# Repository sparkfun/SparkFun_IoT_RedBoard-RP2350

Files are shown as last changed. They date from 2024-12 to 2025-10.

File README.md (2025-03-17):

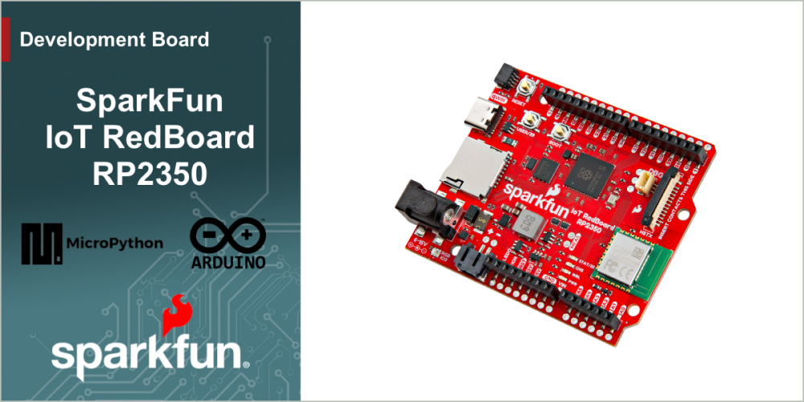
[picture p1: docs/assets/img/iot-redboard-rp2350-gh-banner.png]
SparkFun IoT RedBoard - RP2350) SparkFun IoT RedBoard - RP2350 (https://www.sparkfun.com/sparkfun-iot-redboard-rp2350.html)


[*SparkFun IoT RedBoard - RP2350 (WRL-27708)*](https://www.sparkfun.com/sparkfun-iot-redboard-rp2350.html)

The SparkFun IoT Redboard - RP2350 combines the RP2350 microcontroller with the Raspberry Pi Radio Module 2 to provide a powerful and versatile wireless development platform in the Arduino R4 form factor. This IoT Redboard also includes integrated battery power and charging circuits, &micro;SD card slot, Qwiic connector, 3-pin debug header as well as a 22-pin ribbon cable connector tied to the RP2350's HSTX (high-speed transmit) pins. The board shares a pinout between female headers and matching 0.1"-spaced plated through-hole (PTH) headers to allow you to choose between temporary or soldered connections. 

Repository Contents
-------------------

* **/Documentation** - Data sheets, additional product information
* **/Examples** - Example code
* **/Hardware** - Eagle design files (.brd, .sch)
* **/docs** - GitHub Pages documentation files

Documentation
--------------

* **[Hookup Guide](https://docs.sparkfun.com/SparkFun_IoT_RedBoard-RP2350/)** - Basic hookup guide for the SparkFun IoT RedBoard - RP2350.

Product Versions
----------------

* [WRL-27708](https://www.sparkfun.com/sparkfun-iot-redboard-rp2350.html) - Initial release of the IoT RedBoard - RP2350

License Information
-------------------

This product is ***open source***!

Please review the LICENSE.md file for license information.

If you have any questions or concerns on licensing, please contact technical support on our [SparkFun forums](https://forum.sparkfun.com/viewforum.php?f=152).

Distributed as-is; no warranty is given.

* Your friends at SparkFun.

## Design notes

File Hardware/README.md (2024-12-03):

SparkFun <PRODUCT NAME> Design Files
=====================================

The .sch and .brd files hare are Eagle CAD schematic and PCB design files from SparkFun Electronics.
A freeware version of Autodesk Eagle can be found [here](https://www.autodesk.com/products/eagle/free-download).

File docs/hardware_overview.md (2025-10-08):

This document gives a detailed overview of the RedBoard IoT - RP2350 and all components present on the board.

## IoT RedBoard - RP2350 Overview

The IoT RedBoard - RP2350 is packed with hardware aimed at helping users get the most out of the RP2350. This includes multiple power inputs like USB-C and a 2-pin JST connector, Qwiic connector, standard R3 female headers, several status LEDs and also a couple specialized headers for the RP2350's high-speed transmit (HSTX) pins and its debug pins. The photo below highlights most of the major components on this board that we'll cover in this Hardware Overview.

<figure markdown>
Photo highlighting major components on the IoT RedBoard - RP2350
</figure>

## RP2350 Microcontroller

The RP2350 from Raspberry Pi packs a whole lot of computing punch in a tiny package. The RP2350 is a unique dual-core microcontroller that has <i>four</i> internal processors (two Arm Cortex-M33 and two Hazard3 RISC-V processors @150 MHz), though you can only select any two of these four to run at the same time. 

This internal configuration allows users to customize the chip to use a pair their preferred architecture (ARM or Hazard3) or to use one of each! The RP2350 includes 520kB of on-chip SRAM in ten independent banks, 8kB of one-time-programmable (OTP) storage and this board also includes PSRAM connected to the chip's QSPI bus. The RP2350 also has a bevy of security features including optional boot signing with protected OTP storage for the boot decryption key, global bus filtering (based on either Arm or RISC-V security and privilege levels) and more.

The RedBoard IoT - RP2350 uses the "B" version of the microcontroller which has 48 5V-tolerant GPIO with 8 analog inputs and also includes the following peripheral options:

* 2x UART
* 2x SPI
* 2x I<sup>2</sup>C
* 24 PWM
* USB 1.1 Controller
* 12 PIO State Machines
* 1x High-Speed Transmit (HSTX) Peripheral for DVI/DSI support

For complete information on the RP2350, refer to the [datasheet](./assets/component_documentation/rp2350-datasheet.pdf).

## Memory

### W25Q128 Flash

The W25Q128 Flash IC adds 16MB of storage space on the RedBoard IoT. This connects to the RP2350 over QSPI.

### PSRAM

The board also includes an 8MB PSRAM IC for dynamic storage. This also connects to the RP2350 over QSPI. PSRAM support is included in the SparkFun MicroPython "early release" firmware found later in this guide and on the product page, but is not natively supported in the Pico SDK as of release. Refer to the Arducam Demo section of this guide for information on how to enable and set up PSRAM using the Pico SDK.

For a complete overview of the PSRAM IC, refer to the [datasheet](./assets/component_documentation/APS6404L_3SQR_Datasheet.pdf).

### &micro;SD Card Slot

The board has a &micro;SD card slot that connects to the RP2350's SPI bus for even more storage. Make sure the SPI are **LOW** when the &micro;SD card is **unpowered**. Setting these pins **HIGH** can damage the GPIO pins. The connector is a fricton-fit connector so no "clicking" and "unclicking" is necessary. Just plug it in nice and snug. 

## Raspberry Pi RM2 Radio Module

The Raspberry Pi RM2 (radio module 2) is built around the same chipset as the previous Raspberry Pi radio module found on boards like the Pico W. The module features both WiFi 4 (802.11n) 2.4GHz and  Bluetooth<sup>&trade;</sup> 5.2 with support for Low Energy (Central and Peripheral) and Classic. 

The RM2 communicates with the RP2350 over SPI and we've designed this board to use the same pins for the radio module as official Raspberry Pi boards (Pico W and Pico 2 W), making it easy to use the radio module without having to adjust anything from those development boards. The RedBoard IoT routes the module's GPIO0 pin to a blue STAT LED to allow users to create a visual indicator of the status of the module. We added this STAT LED connected to the same pin used on the Pico W to make code for that compatible with the RedBoard IoT - RP2350.

## Power

The RedBoard IoT - RP2350 includes several options for powering including USB-C, LiPo battery with on-board battery charging and monitoring circuits as well as direct power inputs.

### USB-C

The USB-C connector on the board acts as the primary serial interface for the RP2350 as well as a power input. The <b>5V</b> USB input voltage is regulated down to <b>3.3V</b> through a voltage regulator with a max current of <b>500mA@3.3V</b>.

### Barrel Jack

The barrel jack connector on this board accepts a supply voltage between <b>7V</b> and <b>15V</b>. This supply voltage includes a <b>16V/2.5A/5A</b> fuse.

### LiPo Power & Charging

The IoT RedBoard - RP2350 can also be powered with a single cell lithium battery through a 2-pin JST connector. The board also includes a MCP73831 LiPo charge IC as part of a charging circuit for a connected battery. The charge rate is set to <b>455mA</b> and is powered either via USB, barrel jack or dedicated pin. 

It also has a MAX17048 battery fuel gauge to monitor a connected battery's voltage level. The fuel gauge communicates with the RP2350 over I<sup>2</sup>C.

## Pinout

### R3 Footprint Female Headers

### HSTX Connector

### RP2350 Debug Connector

We've also included a dedicated 1mm 3-pin connector tied to the RP2350's debug pins (SWDIO, SWCK & Ground). Users can plug a [debug cable (link needed - ML)]() to this connector. These pins are also connected to a 0.1"-spaced PTH header right next to it for those who prefer a different connection type. 

## LEDs

This board has four LEDs labeled <b>STAT/25</b>, <b>CHG</b>, <b>WRL</b>, <b>PWR</b> and <b>RGB/IO3</b>.

**Photo highlighting LEDs - ML**

The list below outlines the color and functionality of the LEDs on the IoT RedBoard - RP235.

* <b>STAT/25</b> - Blue LED tied to the RP2350's IO25. User-programmable status LED. 
* <b>CHG</b> - Yellow LED connects to the MCP73831 LiPo charge IC to indicate when an attached battery is being charged.
* <b>WRL</b> - Blue LED tied to IO0 on the RM2. User-programmable status LED.
* <b>PWR</b> - Red LED tied to <b>3.3V</b> power circuit.
* <b>RGB/IO3</b> - WS2812 RGB LED tied to the RP2350's IO3. User-progammable RGB LED.

## Buttons

There are three push buttons on the board labeled <b>RESET</b>, <b>USER/36</b> and <b>BOOT</b>.

**Photo highlighting buttons - ML**

The <b>RESET</b> button connects to the RP2350's RUN pin and resets the RP2350 when pressed. The <b>USER/36</b> button connects to IO36 on the RP2350 and can act as a physical input to trigger an event in code. The <b>BOOT</b> button 

## Solder Jumpers

The IoT RedBoard - RP2350 has five solder jumpers labeled <b>PWR</b>, <b>LP</b>, <b>SHLD</b>, <b>I2C</b> and <b>BYP</b>. 

**Photo highlighting solder jumpers - ML**

The list below outlines the solder jumpers functionality, default state and any notes about their behavior.

* <b>PWR</b> - Completes the Power LED circuit. CLOSED by default. Open to disable the power LED to help conserve power.
* <b>LP</b> - Pulls the RP9080 3.3V regulator's enable (EN) pin HIGH (3.3V) to power the peripheral (3.3V_P) power circuit. CLOSED by default. While enabled, this provides power to the &micro;SD card and RGB LED. Open to disable the peripheral power circuit.
* <b>SHLD</b> - Nets the USB-C Shield pin to the board's ground plane. CLOSED by default. Open to isolate the shield pin from the board's ground.
* <b>I2C</b> - Three-way jumper pulls the I<sup>2</sup>C pins (IO4/SDA and IO5/SCL) to <b>3.3V</b> through a pair of <b>2.2k&ohm;</b> resistors. CLOSED by default. Open the jumper to disable the pullups on these pins.
* <b>BYP</b> - Fuse bypass jumper. OPEN by default. Close to bypass the fuse on the VIN input.

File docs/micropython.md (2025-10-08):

## Setup

MicroPython is an application of the Python 3 language that runs on microcontrollers like the IoT RedBoard - RP2350 that allows you to easily interact with the board directly over a USB serial interface through either a command line interface or your preferred Python IDE such as [Thonny](https://thonny.org/). We'll do a quick overview of how to download MicroPython firmware on to the RedBoard IoT - RP2350 but for a complete overview of using MicroPython with this and other RP2350 boards, head over to Raspberry Pi's documentation by clicking the button below:

<article style="text-align: center;" markdown>
[Raspberry Pi MicroPython Docs](https://www.raspberrypi.com/documentation/microcontrollers/micropython.html){ .md-button .md-button--primary}
</article>

## UF2 Firmware

The SparkFun IoT RedBoard - RP2350 ships with MicroPython firmware pre-loaded so you do not need to download and install it in your board. If you need to update the firmware at any point, it is available in the main release of MicroPython [here](https://micropython.org/download/). Search for "SparkFun IoT RedBoard - RP2350" on the MicroPython downloads page for the correct firmware. This release does **not** include PSRAM support; if your project requires using PSRAM, you can find a Beta release MicroPython firmware available [here](https://github.com/sparkfun/micropython/releases).

Download the latest release and then put the IoT RedBoard - RP2350 into UF2 bootloader mode and open the location the board appeared as a USB storage device (it should appear as "RP2350"). Next, drag and drop the UF2 file into the RP2350 folder and the board should reboot. After the board reboots, open up your preferred MicroPython IDE (or command line interface) and you can start interacting with your RedBoard IoT. Head over to the Quick Start guide for an example project that shows how to connect the board to a WiFi network, download data from a website and control the RGB LED.

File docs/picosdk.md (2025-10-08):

## Pico SDK Setup & Documentation

The Pico C SDK is a C/C++ development kit for Raspberry Pi microcontrollers including the RP2350. Click on the links below for complete documentation on installing and using the SDK.

<article style="text-align: center;" markdown>
[Pico C SDK Documentation](https://www.raspberrypi.com/documentation/pico-sdk/){ .md-button .md-button--primary }
</article>

<article style="text-align: center;" markdown>
[Pico C SDK GitHub Repository](https://github.com/raspberrypi/pico-sdk){ .md-button .md-button--primary }
</article>

### RedBoard IoT - RP2350 Board Definition

When using the Pico SDK, make sure to use v2.1 or later and select `sparkfun_iotredboard_rp2350` for the board. We recommend using [Microsoft VS Code](https://code.visualstudio.com/) with the [Pico SDK Extension](https://marketplace.visualstudio.com/items?itemName=raspberry-pi.raspberry-pi-pico).

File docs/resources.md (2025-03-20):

For more information on the SparkFun IoT RedBoard - RP2350, check out the following resources:

* [Schematic (PDF)](./assets/board_files/SparkFun_IoT_RedBoard-RP2350.pdf)
* [KiCad Files (ZIP)](./assets/board_files/SparkFun_IoT_RedBoard-RP2350.zip)
* [Board Dimensions](./assets/board_files/SparkFun_IoT_RedBoard-RP2350-Dimensions.jpg)
* [RP2350 Datasheet](./assets/component_documentation/rp2350-datasheet.pdf)
* [GitHub Repository](https://github.com/sparkfun/SparkFun_IoT_RedBoard-RP2350)

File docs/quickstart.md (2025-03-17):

Welcome to the SparkFun IoT RedBoard - RP2350 Quick Start Guide showing how to set up and use the RM2 wireless chip to connect to a WiFi network, request and download data on the number and names of astronauts currently on the International Space Station. 

If you're not familiar with using development boards or the development environments covered in this guide, refer to the [Hardware](./hardware_overview.md) & [Software](./uf2.md) sections for a detailed overview of the board along with instructions on setting up and programming the IoT RedBoard - RP2350.

## Basic Assembly

Start by plugging the IoT RedBoard - RP2350 into your computer using a USB-C connector. 

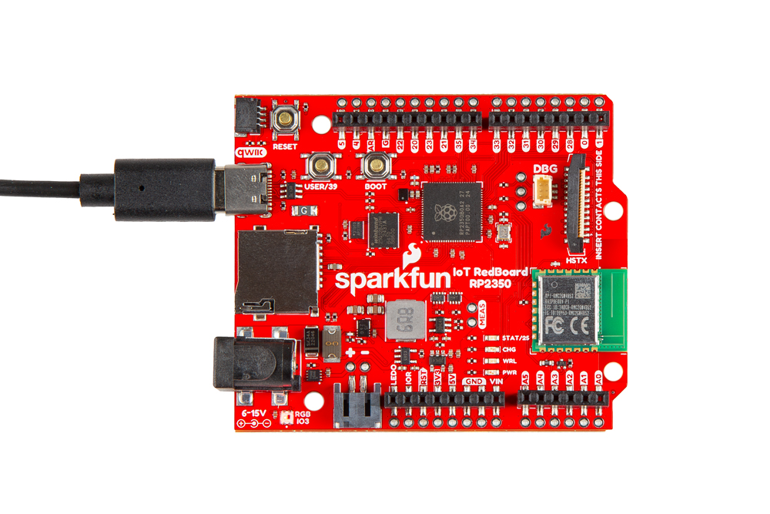
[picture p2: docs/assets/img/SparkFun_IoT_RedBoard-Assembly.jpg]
Photo showing RedBoard IoT - RP2350 connected over USB-C


## Code Examples

The following examples for both MicroPython and Arduino can be found in the Examples folder [here](https://github.com/sparkfun/SparkFun_IoT_RedBoard-RP2350/tree/main/Examples) in the GitHub repository. They demonstrate how to connect the IoT RedBoard - RP2350 to a WiFi network and then request and download data on the number of astronauts currently in space. They also include a visual indicator of the connection status using the RGB LED on the board like the photos below show:

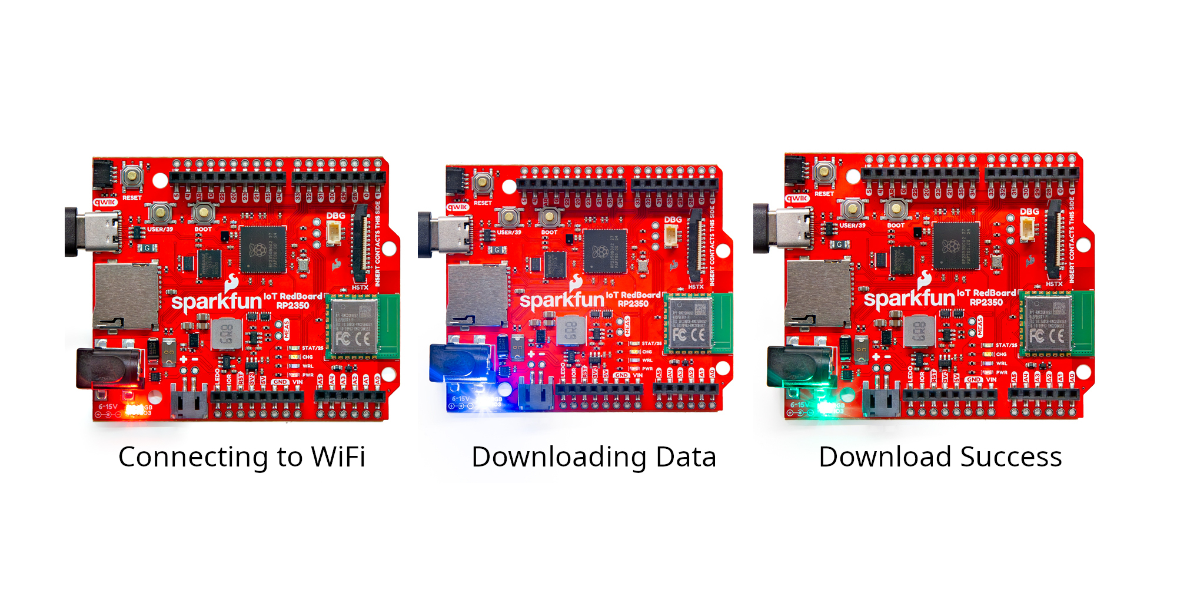
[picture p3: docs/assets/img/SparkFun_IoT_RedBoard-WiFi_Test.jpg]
Photo showing RGB LED indications during WiFi test.


### MicroPython

The IoT RedBoard - RP2350 ships with MicroPython firmware pre-loaded on the board. If needed, you can find the latest release of the firmware [here](https://github.com/sparkfun/micropython/releases). Open and run the Astronaut Network Demo in MicroPython by following these steps:

* Ensure you have a Python IDE like [Thonny](https://thonny.org/) installed or use a Command Line Interface (CLI) if you prefer.
* Download and open the [Astronaut Network Demo](https://github.com/sparkfun/SparkFun_IoT_RedBoard-RP2350/blob/main/Examples/Astronaut_Network_Demo_mpy/Astronaut_Network_Demo_mpy.py) in your preferred Python IDE (or CLI).
* Adjust values for `WIFI_NETWORK` and `WIFI_PASSWORD` to your network's credentials.
* Run the example.
* Watch the serial print out for status updates along with the RGB cycling from red to blue and then green.

**Code to Note**:

* Required modules for the example:
``` py
import network
import urequests
import time
import neopixel
import machine
```

* LED control. Values are (R,G,B) 0-255. This sets the LED to full Red:
``` py
led[0] = (255, 0, 0)
led.write()
```

* WiFi network connection. Enter values for network ID and password:
```py
wlan = network.WLAN(network.STA_IF)
wlan.active(True)
wlan.connect('WIFI_NETWORK', 'WIFI_PASSWORD')
```
Serial print and download request for the list of astronauts currently in space: 
```py
print('Downloading list of astronauts currently in space...')
astronauts = urequests.get("https://corquaid.github.io/international-space-station-APIs/JSON/people-in-space.json").json()
```

* Serial print of the number of and names of astronauts:
```py
# Print the number of astronauts and their names
number = astronauts['number']
print('There are', number, 'astronauts in space.')
for i in range(number):
    print(i+1, astronauts['people'][i]['name'])
```

### Arduino IDE

Run the Astronaut Network Demo using the [Arduino IDE](https://www.arduino.cc/en/software) by following these steps:

* Download and open the [Astronaut Network Demo](https://github.com/sparkfun/SparkFun_IoT_RedBoard-RP2350/blob/main/Examples/Astronaut_Network_Demo/Astronaut_Network_Demo.ino) sketch in Arduino.
* Open the [Board Manager](https://docs.arduino.cc/software/ide-v2/tutorials/ide-v2-board-manager/) and search for "Arduino Pico" to install the [Arduino-Pico](https://github.com/earlephilhower/arduino-pico) package.
* Open the [Library Manager](https://docs.arduino.cc/software/ide-v2/tutorials/ide-v2-installing-a-library/) and search for "FastLED" to install the [FastLED Arduino Library](https://github.com/FastLED/FastLED)
* Adjust the WiFi variables ("SSID" and "PASSWORD") to your network's credentials.
* Select the board (SparkFun IoT RedBoard - RP2350) and Port and click the "Upload" button.
* On upload completion, open the [Serial Monitor](https://docs.arduino.cc/software/ide-v2/tutorials/ide-v2-serial-monitor/) with the baud set to **115200** and watch the serial printout along with the RGB LED cycling from red to blue and then green.

The example includes several serial prints to indicate success or failure. If the code fails at any point, refer to the associated serial print to help identify where it failed and why.

**Code to Note**:

* WiFi network variables. Adjust "SSID" and "PASSWORD" to your WiFi network's ID and password:
```c++
#ifndef STASSID
#define STASSID "SSID"
#define STAPSK  "PASSWORD"
#endif // !STASSID
```

* WS2812 LED pin definition and settings:
```c++
#define NUM_LEDS 1
#define DATA_PIN PIN_NEOPIXEL
#define LED_TYPE WS2812
#define COLOR_ORDER GRB
#define LED_BRIGHTNESS 30
```

* Attempt to connect to WiFi network:
```c++
multi.addAP(ssid, password);

    if(multi.run() != WL_CONNECTED) {
        Serial.println(F("Unable to connect to network, rebooting in 10 seconds..."));
        delay(10000);
        rp2040.reboot();
    }

    Serial.println(F("Connected to network"));
    Serial.println(F("IP address: "));
    Serial.println(WiFi.localIP());
```

* Send HTTP get request:
```c++
 client.println(F("GET /international-space-station-APIs/JSON/people-in-space.json HTTP/1.0"));
    client.println(F("Host: corquaid.github.io"));
    client.println(F("Connection: close"));
```

* Parse JSON request:
```c++
JsonDocument doc;
    DeserializationError error = deserializeJson(doc, client);
    if(error) {
        Serial.print(F("deserializeJson() failed: "));
        Serial.println(error.f_str());
        client.stop();
        return;
    }
```

* Print number & names of astronauts in space:
```c++
int numberOfPeople = doc[F("number")];

    Serial.print(F("There are "));
    Serial.print(numberOfPeople);
    Serial.println(F(" astronauts in space."));

    for(JsonObject people_item : doc[F("people")].as<JsonArray>()) {
        int people_item_id = people_item[F("id")];
        const char* people_item_name = people_item[F("name")];
        Serial.print(people_item_id);
        Serial.print(F(": "));
        Serial.println(people_item_name);
    }
```

## Going Further

If you're looking for more detailed information on the design and components on this IoT Redboard, read on to the Hardware section below. Similarly, the Software tab includes detailed instructions on installing and using all supported development environments along with a few more examples for each IDE. Finally, the Resources section includes the board design files and datasheets for major components on the board.

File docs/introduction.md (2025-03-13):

SparkFun IoT RedBoard - RP2350) SparkFun IoT RedBoard - RP2350

The IoT RedBoard - RP2350 combines the RP2350 microcontroller with the Raspberry Pi Radio Module 2 to provide a powerful and versatile wireless development platform in the Arduino R4 form factor. In this guide we'll cover how to connect the IoT RedBoard - RP2350 to a computer and how to progam it three development environments: Raspberry Pi Pico SDK, MicroPython, or Arduino.

This guide uses just the hardware present on the IoT RedBoard - RP2350 so in order to follow along with this tutorial you'll only need the following items:

* [IoT RedBoard - RP2350](https://www.sparkfun.com/sparkfun-iot-redboard-rp2350.html)
* [USB-C Cable](https://www.sparkfun.com/usb-a-to-usb-c-cable-1m-usb-2-0-flexible-silicone.html)

## Topics Covered

This document contains three main sections: **Quickstart Guide**, **Hardware** and **Software**. 

The Quickstart Guide assumes a working knowledge of how to use a development board and the required software to program them for your project's needs. It covers a quick assembly and then jumps right into getting the necessary software packages installed to start uploading code in just a few short minutes.

The Hardware page provides a detailed overview of the IoT RedBoard - RP2350 along with all the major components included on the board. Refer to this page for information on things like the RP2350, LEDs, pinout and solder jumpers.

The Software pages are split into each supported development environment along with a page that goes into detail on what the UF2 bootloader is and how to use it on the IoT RedBoard - RP2350. Each software page gives instructions on how to download install its respective development environment, any necessary support packages including board definitions and, where necessary, library packages.

## Resources and Support Documentation 

You'll find the board design files (KiCad files & schematic), relevant documentation (datasheets, white papers, etc.) and other helpful links in the **Resources**. Lastly, the **Support** section includes a Troubleshooting page that includes any helpful tips specific to this board as well as information on how to receive technical support from SparkFun.

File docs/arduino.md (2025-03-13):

!!! attention
	If this is your first time using Arduino, please read through our tutorial on [installing the Arduino IDE](https://learn.sparkfun.com/tutorials/installing-arduino-ide). If you have not installed an Arduino library before, we recommend you check out our [installation guide](https://learn.sparkfun.com/tutorials/installing-an-arduino-library).

## Arduino-Pico Boards

The SparkFun IoT RedBoard - RP2350 is supported on the Arduino IDE in the [Arduino-Pico](https://github.com/earlephilhower/arduino-pico) boards package. To install the package, open the Preferences menu by navigating to <b>File</b> > <b>Preferences</b>. Look at the bottom of the Preferences menu for "Additional boards manager URLS" and then copy this JSON link into that field:

<code>
    https://github.com/earlephilhower/arduino-pico/releases/download/global/package_rp2040_index.json
</code>

Click "OK" to close this menu then navigate to the Boards Manager tool and search for "pico" and download the latest release of "Raspberry Pi Pico" (4.2.1 or later).

<figure markdown>
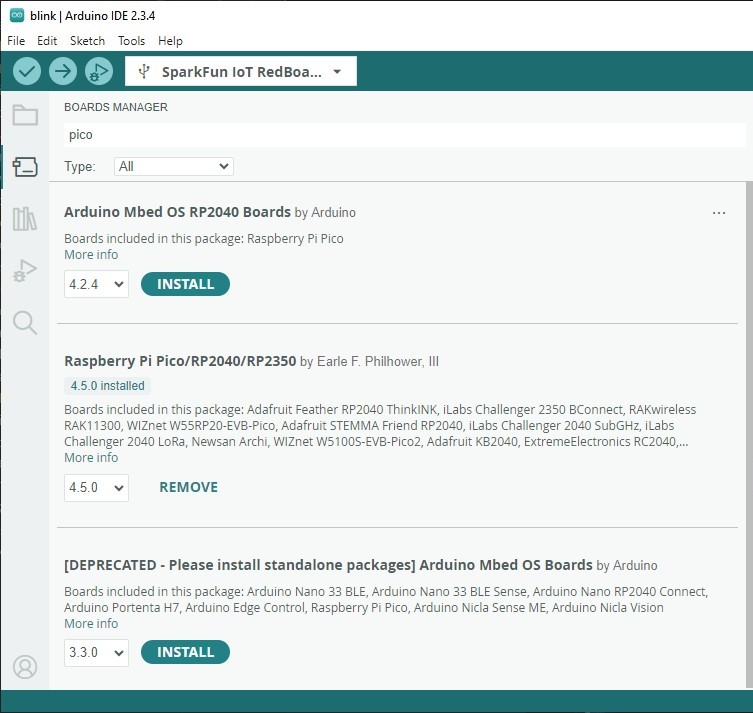
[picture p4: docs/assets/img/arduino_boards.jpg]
Screenshot of board manager tool searching for pico.

</figure>

For more information on using the Arduino-Pico boards package, check out their [documentation page](https://arduino-pico.readthedocs.io/en/latest/index.html). Head over to the Quick Start guide for an Arduino example demonstrating how to connect to a WiFi network, download data from a site and control the RGB LED.

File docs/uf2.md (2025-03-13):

The IoT RedBoard - RP2350 uses a UF2 bootloader for easy flashing/uploading of code to the board. The UF2 bootloader causes the board to show up on your computer as a USB storage device and does <b>not</b> require any drivers for Windows, Mac OSX, and Linux! This bootloader is used for uploading in both the Pico SDK and MicroPython development environments so let's take a brief look at how to enter bootload mode.

## What is UF2?

UF2 stands for USB Flashing Format, which was developed by Microsoft for PXT (now known as MakeCode) for flashing microcontrollers over the Mass Storage Class (MSC), just like a removable flash drive. The file format is unique, so unfortunately, you cannot simply drag and drop a compiled binary or hex file onto the board. Instead, the format of the file has extra information to tell the processor where the data goes, in addition to the data itself. For more information about UF2, you can read more from the [MakeCode blog](https://makecode.com/blog/one-chip-to-flash-them-all), as well as the [UF2 file format specification](https://github.com/Microsoft/uf2).

## Entering the Bootloader

Putting the IoT RedBoard - RP2350 into bootloader mode only requires a couple of presses of the BOOT and RESET buttons. Enter the bootloader with the following steps:

* Press and hold down the BOOT button.
* While holding BOOT button, press and release the RESET button.
* Release the BOOT button
* Device should appear as a USB storage device called "RP2350"

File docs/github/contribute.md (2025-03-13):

# Contribute: Make an Augmentation!
Spot an improvement opportunity? Feel free to contribute to our open-source design and documentation. 

## :material-file-document-multiple:&nbsp;Improve our Documentation
All of this documentation can be modified by you! Please help us make it better.

* These pages are contained in the [`docs` folder](https://github.com/sparkfun/SparkFun_IoT_RedBoard_RP2350/tree/main/docs) of the [SparkFun IoT RedBoard repository](https://github.com/sparkfun/SparkFun_IoT_RedBoard_RP2350).

<!-- ### :material-source-pull:&nbsp;Submit a Correction -->
### Submit a Correction

1. With a GitHub account, [fork this repository](https://github.com/sparkfun/SparkFun_IoT_RedBoard_RP2350/fork).
2. Add your corrections or improvements to the markdown file.
3. File a pull request with your changes, and enjoy making the ~~words~~ ~~worlds~~ world a better place.
	* Once received, the documentation specialist will automatically be notified.
	* We will review your suggested improvements to make sure they are correct and fit within our documentation standards.

## :material-cog:&nbsp;Improve our Hardware Design
All of our designs are open-source! Please help us make it better.

* Our board design files are contained in the [`Hardware` folder](https://github.com/sparkfun/SparkFun_IoT_RedBoard_RP2350/tree/main/Hardware) of the [<Official Product Name> repository](https://github.com/sparkfun/SparkFun_IoT_RedBoard_RP2350).

<!-- ### :material-source-pull:&nbsp;Submit a Design Enhancement -->
### Submit a Design Enhancement

1. With a GitHub account, [fork this repository](https://github.com/sparkfun/SparkFun_IoT_RedBoard_RP2350/fork).
2. Add your design augmentation(s)
3. File a pull request with your changes, and enjoy making the ~~words~~ ~~worlds~~ world a better place.
	1. Once received, the engineer in charge of the original design will automatically be notified.
	2. We will review your suggested improvement(s) to verify that they are within our board design standards and meet our product design requirements.
	3. If approved, we will flag these changes for our next board revision. Congrats! 🍻

		!!! info
			Even if your suggestion is accepted, these changes may not be immediately available for purchase. We may have to cycle through our current product inventory first.

## Contributors&nbsp;:clap:
Let's provide some recognition to the contributors for this project!

GitHub Contributors Image
<br>


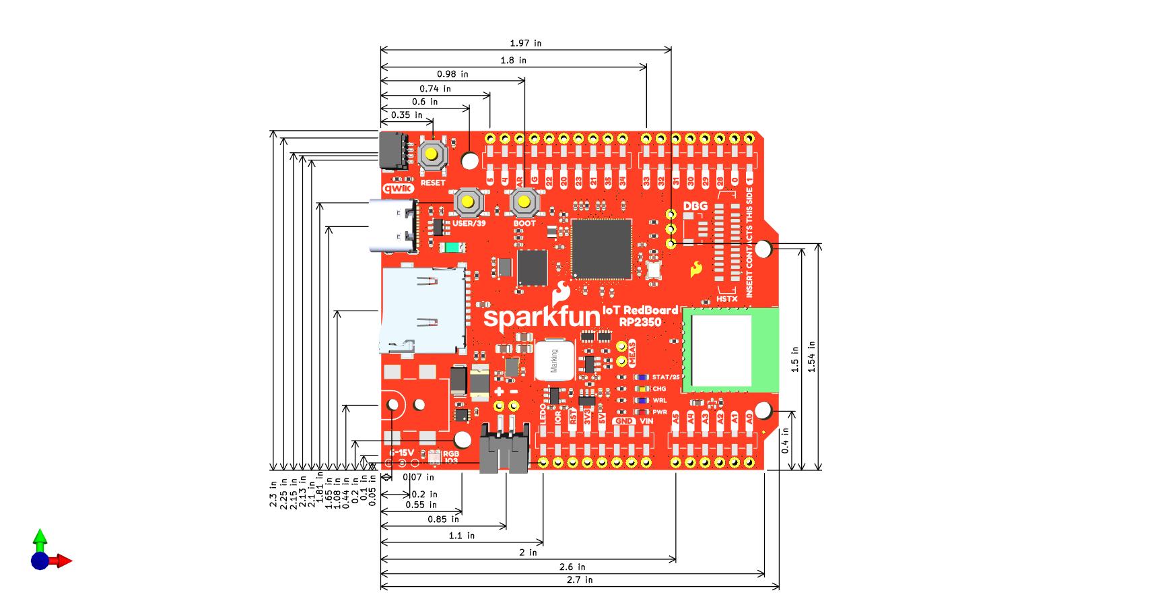
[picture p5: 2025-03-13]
docs/assets/board_files/SparkFun_IoT_RedBoard-RP2350-Dimensions.jpg

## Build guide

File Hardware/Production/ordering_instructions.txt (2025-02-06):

Ordering Instructions:
Panel dimensions: 390.18 x 131.54 mm.
Controlled Impedance: JLC7628
Material: TG155
Solder Mask: Red
Silkscreen Color: White
Layers: 4
Finish: Lead-Free HASL
Thickness: 1.6mm
Inner Copper Weight: 0.5oz
Outer Copper Weight: 1oz
Minimum track width: 0.12mm (4.72mil)
Minimum via drill: 0.20mm (7.87mil)
No Clean Process

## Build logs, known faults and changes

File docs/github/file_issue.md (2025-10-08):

# Did we make a mistake?

Spot something wrong? Please let us know. 

<!-- Technical Assistance Box -->
!!! warning "Need Help?"
    If you need technical assistance or more information on a product that is not working as you expected, we recommend heading on over to the [SparkFun Technical Assistance](https://www.sparkfun.com/technical_assistanc) page for some initial troubleshooting. This **Submit Issues** page is not where users should seek assistance.

    <article style="text-align: center;" markdown>
    [SparkFun Technical Assistance Page](https://www.sparkfun.com/technical_assistance){ .md-button .md-button--primary }
    </article>
    
    If you can't find what you need there, the [SparkFun Forums](https://forum.sparkfun.com/index.php) is a great place to search the product forums and ask questions.
    
    !!! info "Account Registration Required"
        For your first visit to our forum, you'll need to create a [Forum Account](https://forum.sparkfun.com/ucp.php?mode=register) to post questions.

## Discrepancies in the Documentation

All of our documentation can be modified by you! Please help us make it better.

* The documentation files for these pages are contained in the [`docs` folder](https://github.com/sparkfun/SparkFun_IoT_RedBoard_RP2350/tree/main/docs) of the [<Official Product Name> repository](https://github.com/sparkfun/SparkFun_IoT_RedBoard_RP2350).

### 🔍 Spot something wrong?

If a section of the documentation is incorrect, please [open an issue](https://github.com/sparkfun/SparkFun_IoT_RedBoard_RP2350/issues) and let us know.

### Do you have a suggested correction?

1. With a GitHub account, [fork this repository](https://github.com/sparkfun/SparkFun_IoT_RedBoard_RP2350/fork).
2. Add your correction(s) or improvement(s) to the markdown file(s)
3. File a pull request with your changes, and enjoy making the ~~words~~ ~~worlds~~ world a better place.
	* Once received, the documentation specialist will automatically be notified.
	* We will review your suggested improvement(s) to make sure they are correct and fit within our documentation standards.

## Problems in the Hardware Design

All of our designs are open-source! Please help us make it better.

* Our board design files are contained in the [`Hardware` folder](https://github.com/sparkfun/SparkFun_IoT_RedBoard_RP2350/tree/main/Hardware) of the [<Official Product Name> repository](https://github.com/sparkfun/SparkFun_IoT_RedBoard_RP2350).

### Does something not make sense? 🤔

If part of the design is confusing, please [open an issue](https://github.com/sparkfun/SparkFun_IoT_RedBoard_RP2350/issues) and let us know.

### Did we forget to include an important function of the board? 🤦

If part of the board's functionality is missing, please [open an issue](https://github.com/sparkfun/SparkFun_IoT_RedBoard_RP2350/issues) and file a feature request.

!!! tip "Design Considerations"
	Please keep in mind that we may intentionally exclude certain functions of the board to meet our product design requirements.
	
	* *For example, our Qwiic Micro boards are intended to fit on a small board layout and only use I<sup>2</sup>C communication; therefore, we may not have the SPI and interrupt pins available for users.*

### Do you wish to contribute directly to improving the board design?

1. With a GitHub account, [fork this repository](https://github.com/sparkfun/SparkFun_IoT_RedBoard_RP2350/fork).
2. Add your design augmentation(s)
3. File a pull request with your changes, and enjoy making the ~~words~~ ~~worlds~~ world a better place.
	1. Once received, the engineer in charge of the original design will automatically be notified.
	2. We will review your suggested improvement(s) to verify that they are within our board design standards and meet our product design requirements.
	3. If approved, we will flag these changes for our next board revision. Congrats! 🍻

		!!! info
			Even if your suggestion is accepted, these changes may not be immediately available for purchase. We may have to cycle through our current product inventory first.

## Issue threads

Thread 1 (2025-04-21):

Redboard definition missing from pico-sdk repo

TylerBovenzi, 2025-04-21:
It seems sparkfun_iotredboard_rp2350 is missing from the pico-sdk repo. As a result, I'm unable to add the board using the vscode extension. I am using v2.1.

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

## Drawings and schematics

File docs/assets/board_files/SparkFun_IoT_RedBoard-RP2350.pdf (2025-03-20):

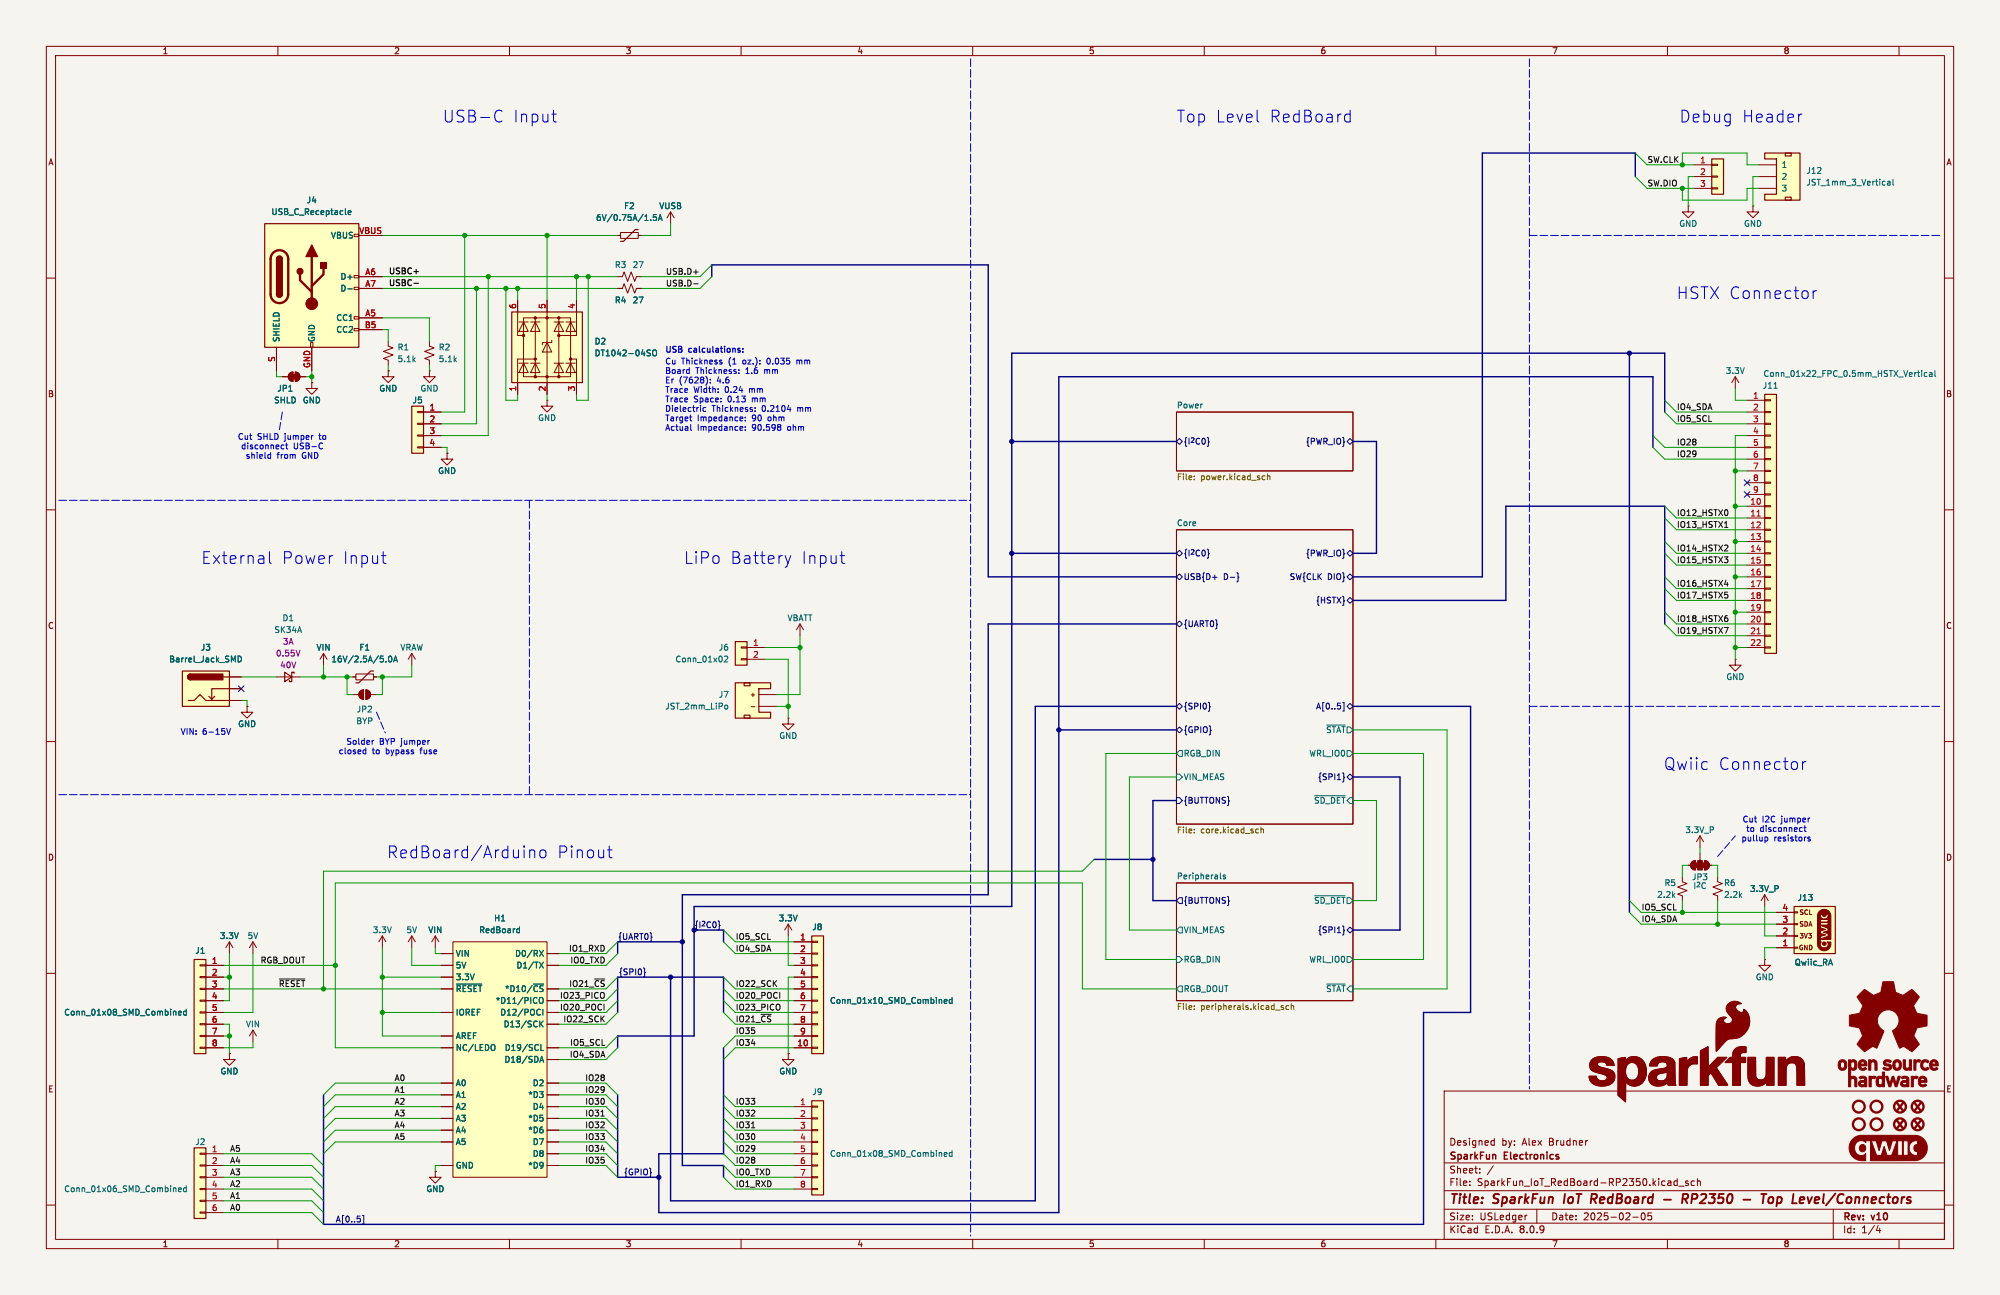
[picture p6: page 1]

Debug Header
to disconnect pullup resistors HSTX Connector

Cut SHLD jumper to
VIN GND

Peripherals File: peripherals.kicad_sch GND

Qwiic Connector Cut I2C jumper

Id: 1/4 Title: SparkFun IoT RedBoard - RP2350 - Top Level/Connectors

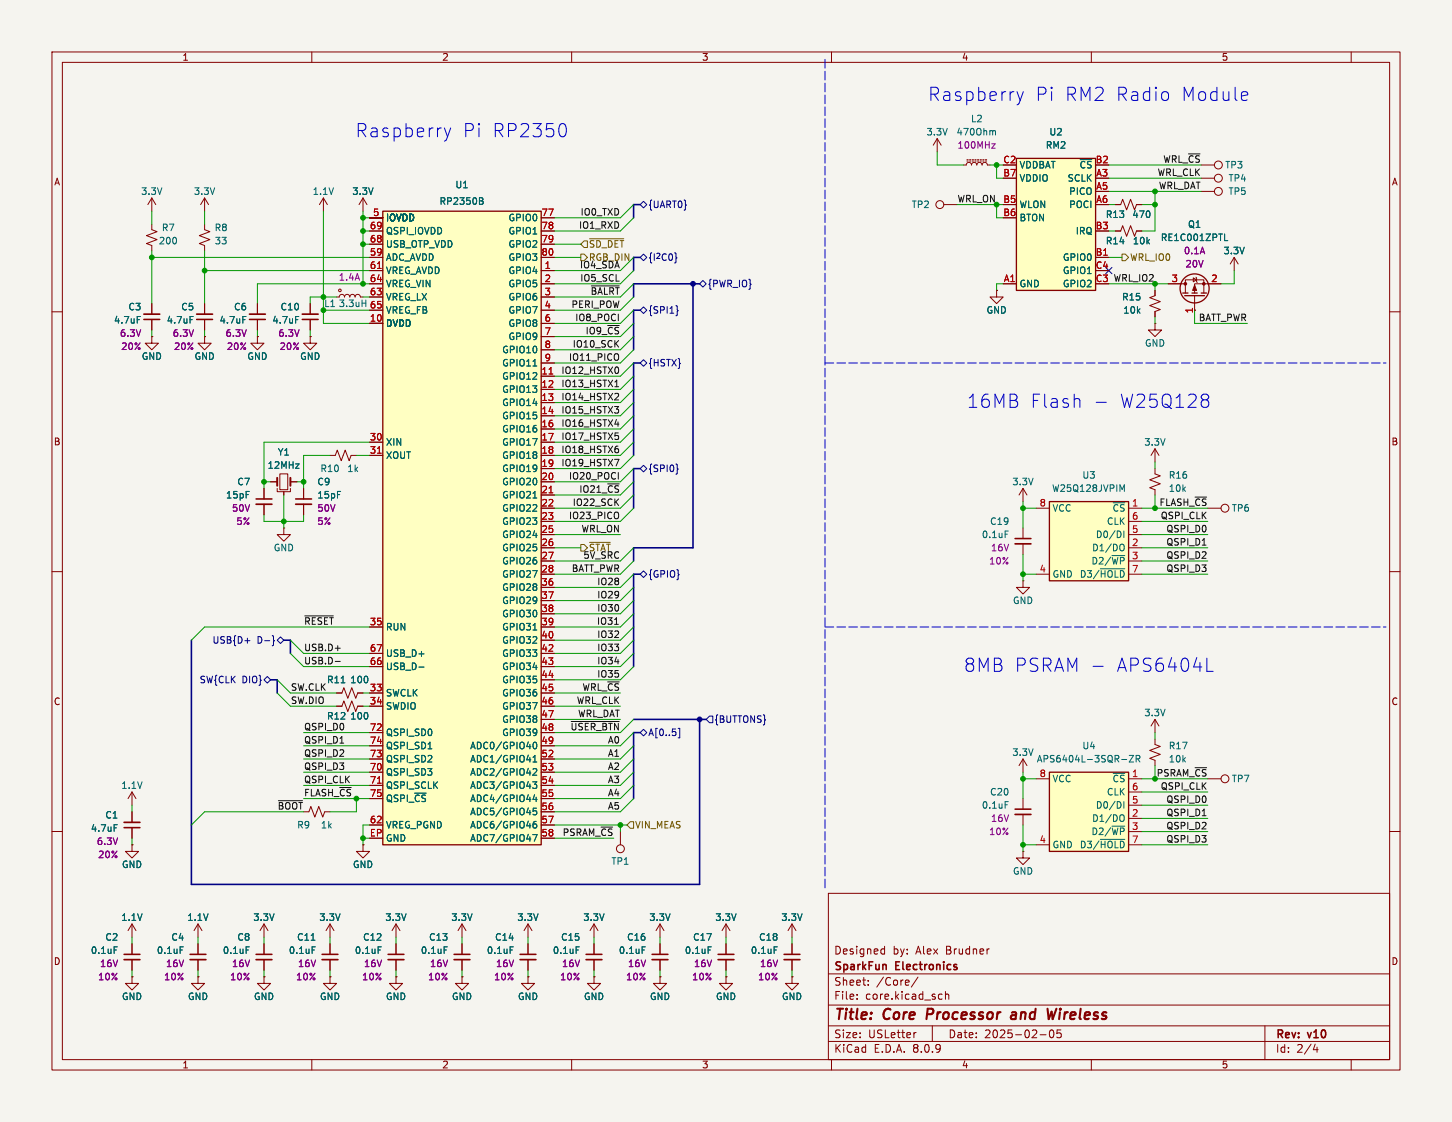
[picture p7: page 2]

Raspberry Pi RM2 Radio Module
GPIO0 77 GPIO1 78 GPIO2 79 GPIO10 8 GPIO3 80 GPIO11 9 GND EP C9

Id: 2/4 Title: Core Processor and Wireless

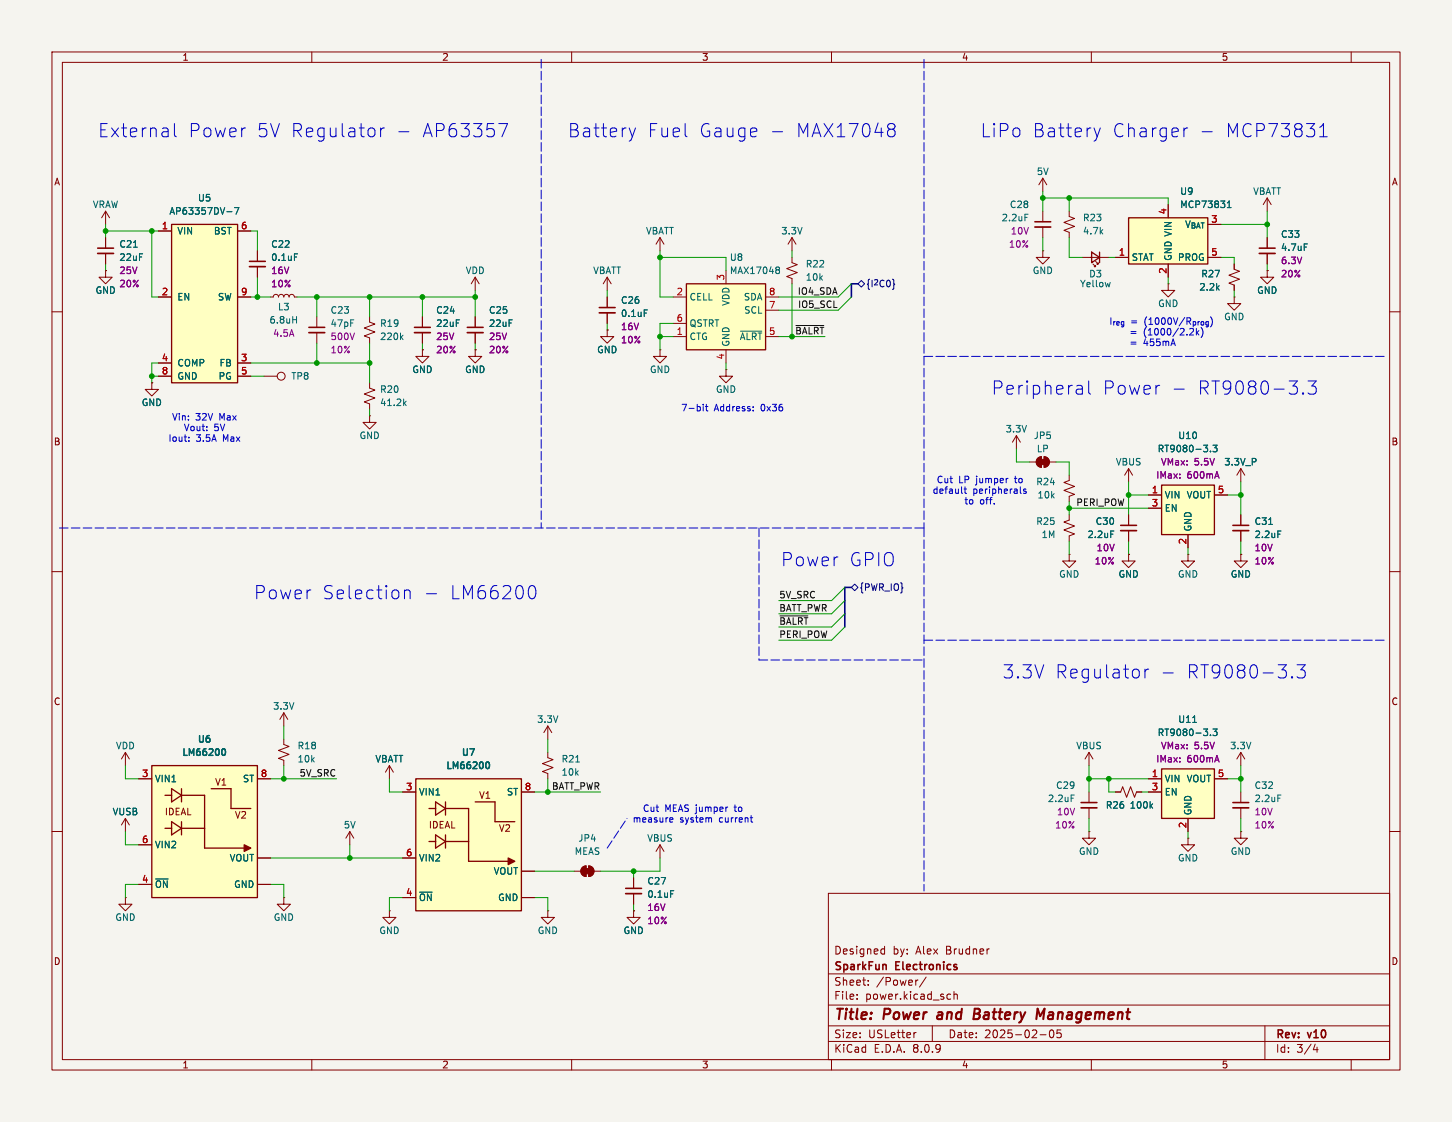
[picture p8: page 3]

to off. Battery Fuel Gauge - MAX17048

4 ~{ALRT}5 QSTRT 6 SCL 7 SDA 8 U8 MAX17048 C28
IO5_SCL PERI_POW

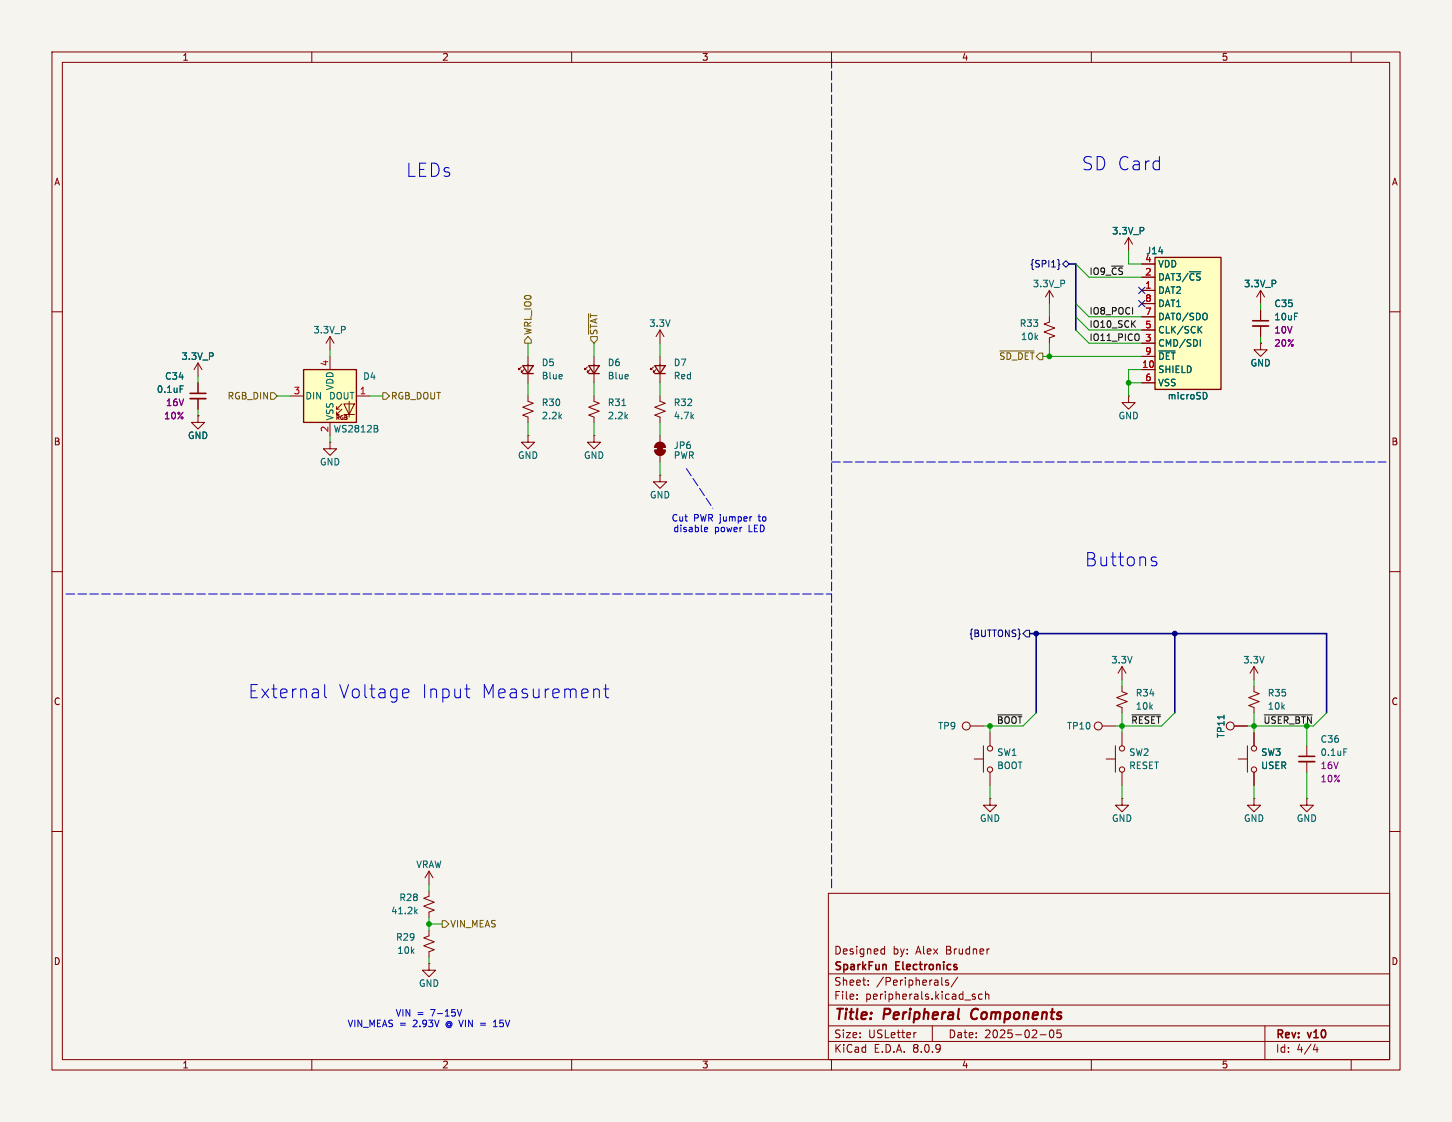
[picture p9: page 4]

Cut PWR jumper to

disable power LED External Voltage Input Measurement

File: peripherals.kicad_sch Sheet: /Peripherals/
Id: 4/4 Title: Peripheral Components

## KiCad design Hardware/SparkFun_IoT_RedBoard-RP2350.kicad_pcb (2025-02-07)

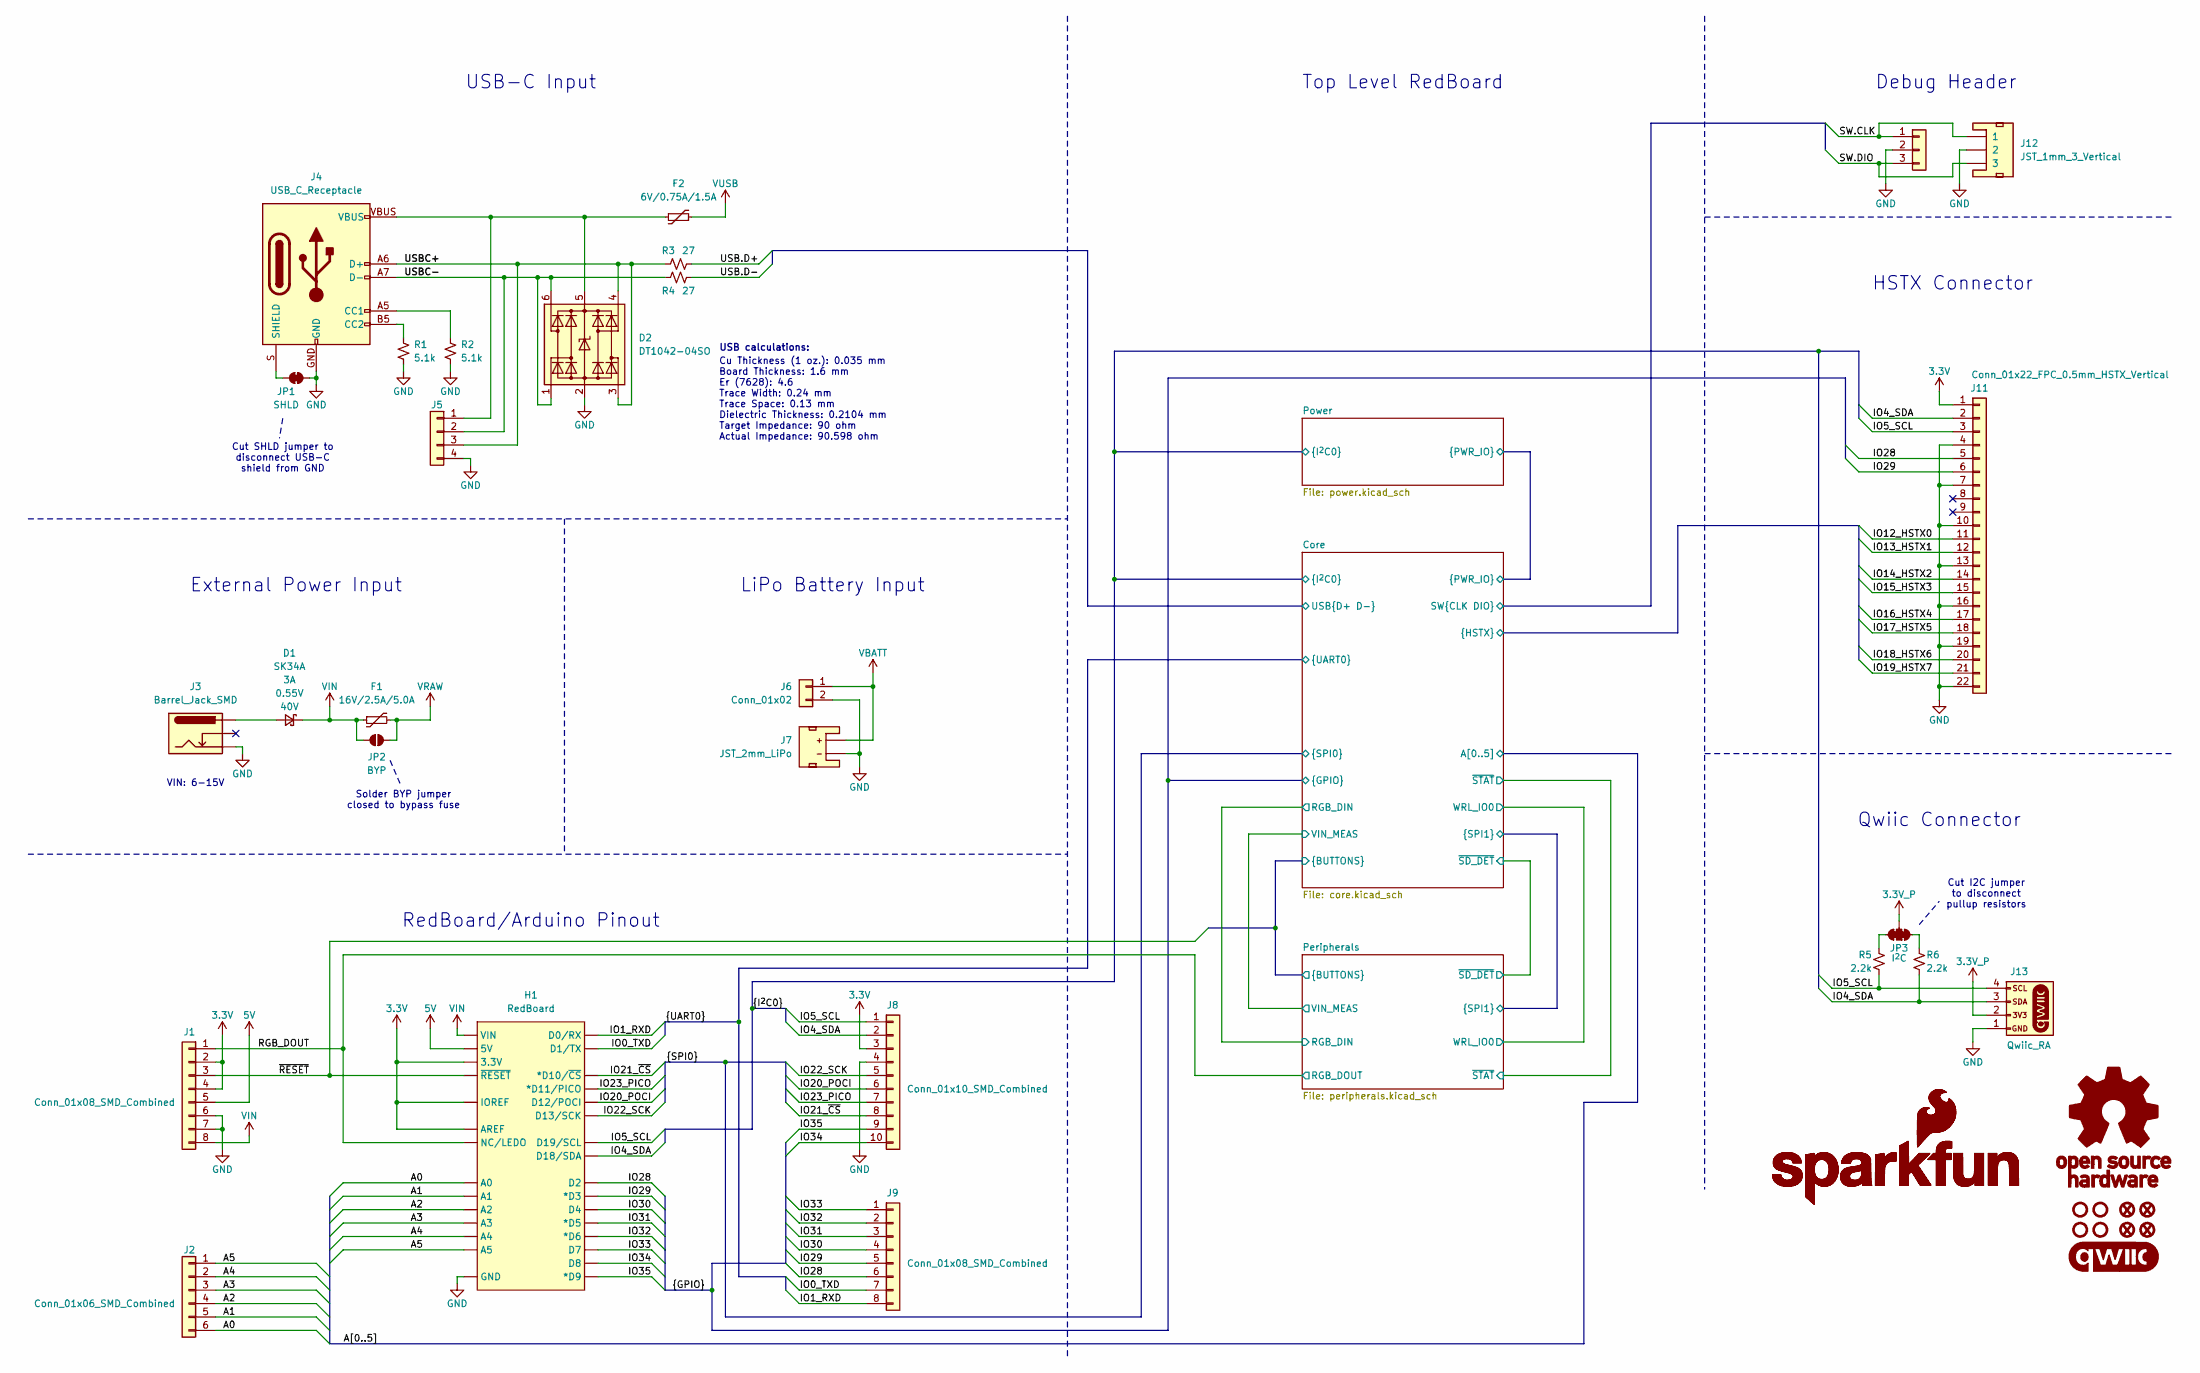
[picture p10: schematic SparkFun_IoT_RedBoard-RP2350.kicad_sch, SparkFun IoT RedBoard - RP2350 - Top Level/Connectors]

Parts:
D1: SK34A; SMA
D2: DT1042-04SO; SOT23-6
F1: 16V/2.5A/5.0A; 1812
F2: 6V/0.75A/1.5A; 1206
FID1, FID2, FID3, FID4: Fiducial_0.5mm; Fiducial_0.5mm_Mask1mm
G1: SparkFun_Logo; SparkFun_Logo_8mm
G2: SparkFun_Logo
G3: OSHW_Logo; Creative_Commons_License
G4: qwiic_Logo
H1: RedBoard
J1, J9: Conn_01x08_SMD_Combined; 1x08_SMD_Combined
J2: Conn_01x06_SMD_Combined; 1x06_SMD_Combined
J3: Barrel_Jack_SMD; Power_Jack_SMD
J4: USB_C_Receptacle; USB-C_16
J5: Conn_01x04_SolderPads; 1x04_Solder_Pads
J6: Conn_01x02; 1x02
J7: JST_2mm_LiPo; JST_SMD_2.0mm-2
J8: Conn_01x10_SMD_Combined; 1x10_SMD_Combined
J10: Conn_01x03; 1x03
J11: Conn_01x22_FPC_0.5mm_HSTX_Vertical; FPC_0.5mm-22_Vertical
J12: JST_1mm_3_Vertical; JST_SMD_1.0mm-3_Vertical
J13: Qwiic_RA; JST_SMD_1.0mm-4_RA
JP1: SHLD; Jumper_2_NC_Trace
JP2: BYP; Jumper_2_NO
JP3: I^{2}C; Jumper_3_NC-2_Trace
R1, R2: 5.1k; R_0402_1005Metric
R3, R4: 27; R_0402_1005Metric
R5, R6: 2.2k; R_0402_1005Metric
ST1, ST2, ST3, ST4: Standoff

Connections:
3.3V: H1.3.3V, H1.AREF, H1.IOREF, J1.2, J1.4, J8.3, J11.1; also elsewhere on the board
3.3V_P: J13.2, JP3.2 (B); also elsewhere on the board
5V: H1.5V, J1.5; also elsewhere on the board
/A0: H1.A0, J2.6; also elsewhere on the board
/A1: H1.A1, J2.5; also elsewhere on the board
/A2: H1.A2, J2.4; also elsewhere on the board
/A3: H1.A3, J2.3; also elsewhere on the board
/A4: H1.A4, J2.2; also elsewhere on the board
/A5: H1.A5, J2.1; also elsewhere on the board
/Core/IO12_HSTX0: J11.11; also elsewhere on the board
/Core/IO13_HSTX1: J11.12; also elsewhere on the board
/Core/IO14_HSTX2: J11.14; also elsewhere on the board
/Core/IO15_HSTX3: J11.15; also elsewhere on the board
/Core/IO16_HSTX4: J11.17; also elsewhere on the board
/Core/IO17_HSTX5: J11.18; also elsewhere on the board
/Core/IO18_HSTX6: J11.20; also elsewhere on the board
/Core/IO19_HSTX7: J11.21; also elsewhere on the board
/Core/SW.CLK: J10.1, J12.1; also elsewhere on the board
/Core/SW.DIO: J10.3, J12.3; also elsewhere on the board
/Core/USB.D+: R3.2; also elsewhere on the board
/Core/USB.D-: R4.2; also elsewhere on the board
/Core/~RESET: H1.~{RESET}, J1.3; also elsewhere on the board
/IO0_TXD: H1.D1 (D1/TX), J9.7; also elsewhere on the board
/IO1_RXD: H1.D0 (D0/RX), J9.8; also elsewhere on the board
/IO4_SDA: H1.D18 (D18/SDA), J8.2, J11.2, J13.3, R6.1; also elsewhere on the board
/IO5_SCL: H1.D19 (D19/SCL), J8.1, J11.3, J13.4, R5.1; also elsewhere on the board
/IO20_POCI: H1.D12 (D12/POCI), J8.6; also elsewhere on the board
/IO21_~CS: H1.D10 (*D10/~CS), J8.8; also elsewhere on the board
/IO22_SCK: H1.D13 (D13/SCK), J8.5; also elsewhere on the board
/IO23_PICO: H1.D11 (*D11/PICO), J8.7; also elsewhere on the board
/IO28: H1.D2, J9.6, J11.5; also elsewhere on the board
/IO29: H1.D3 (*D3), J9.5, J11.6; also elsewhere on the board
/IO30: H1.D4, J9.4; also elsewhere on the board
/IO31: H1.D5 (*D5), J9.3; also elsewhere on the board
/IO32: H1.D6 (*D6), J9.2; also elsewhere on the board
/IO33: H1.D7, J9.1; also elsewhere on the board
/IO34: H1.D8, J8.10; also elsewhere on the board
/IO35: H1.D9 (*D9), J8.9; also elsewhere on the board
/RGB_DOUT: H1.NC/LEDO, J1.1; also elsewhere on the board
/USBC+: D2.3 (I/O2), D2.4 (I/O3), J4.A6 (D+), J4.B6 (D+), J5.3, R3.1
/USBC-: D2.1 (I/O1), D2.6 (I/O4), J4.A7 (D-), J4.B7 (D-), J5.2, R4.1
GND: D2.2 (GND), H1.GND, J1.6, J1.7, J3.GND, J4.GND, J5.4, J6.2, J7.1 (-), J8.4, J10.2, J11.4, J11.7, J11.10, J11.13, J11.16, J11.19, J11.22, J12.2, J13.1, JP1.2 (B), R1.1, R2.1; also elsewhere on the board
unnamed: D1.A, J3.PWR
unnamed: D2.5 (VCC), F2.1, J4.VBUS, J5.1
unnamed: J4.A5 (CC1), R2.2
unnamed: J4.B5 (CC2), R1.2
unnamed: J4.S (SHIELD), JP1.1 (A)
unnamed: JP3.1 (A), R6.2
unnamed: JP3.3 (C), R5.2
VBATT: J6.1, J7.2 (+); also elsewhere on the board
VIN: D1.C (K), F1.1, H1.VIN, J1.8, JP2.1 (A)
VRAW: F1.2, JP2.2 (B); also elsewhere on the board
VUSB: F2.2; also elsewhere on the board

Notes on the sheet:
Qwiic Connector
Top Level RedBoard
Cut SHLD jumper to disconnect USB-C shield from GND
USB calculations:
VIN: 6-15V
Debug Header
External Power Input
Cut I2C jumper to disconnect pullup resistors
HSTX Connector
RedBoard/Arduino Pinout
USB-C Input
LiPo Battery Input
Cu Thickness (1 oz.): 0.035 mm Board Thickness: 1.6 mm Er (7628): 4.6 Trace Width: 0.24 mm Trace Space: 0.13 mm Dielectric Thickness: 0.2104 mm Target Impedance: 90 ohm Actual Impedance: 90.598 ohm
Solder BYP jumper closed to bypass fuse

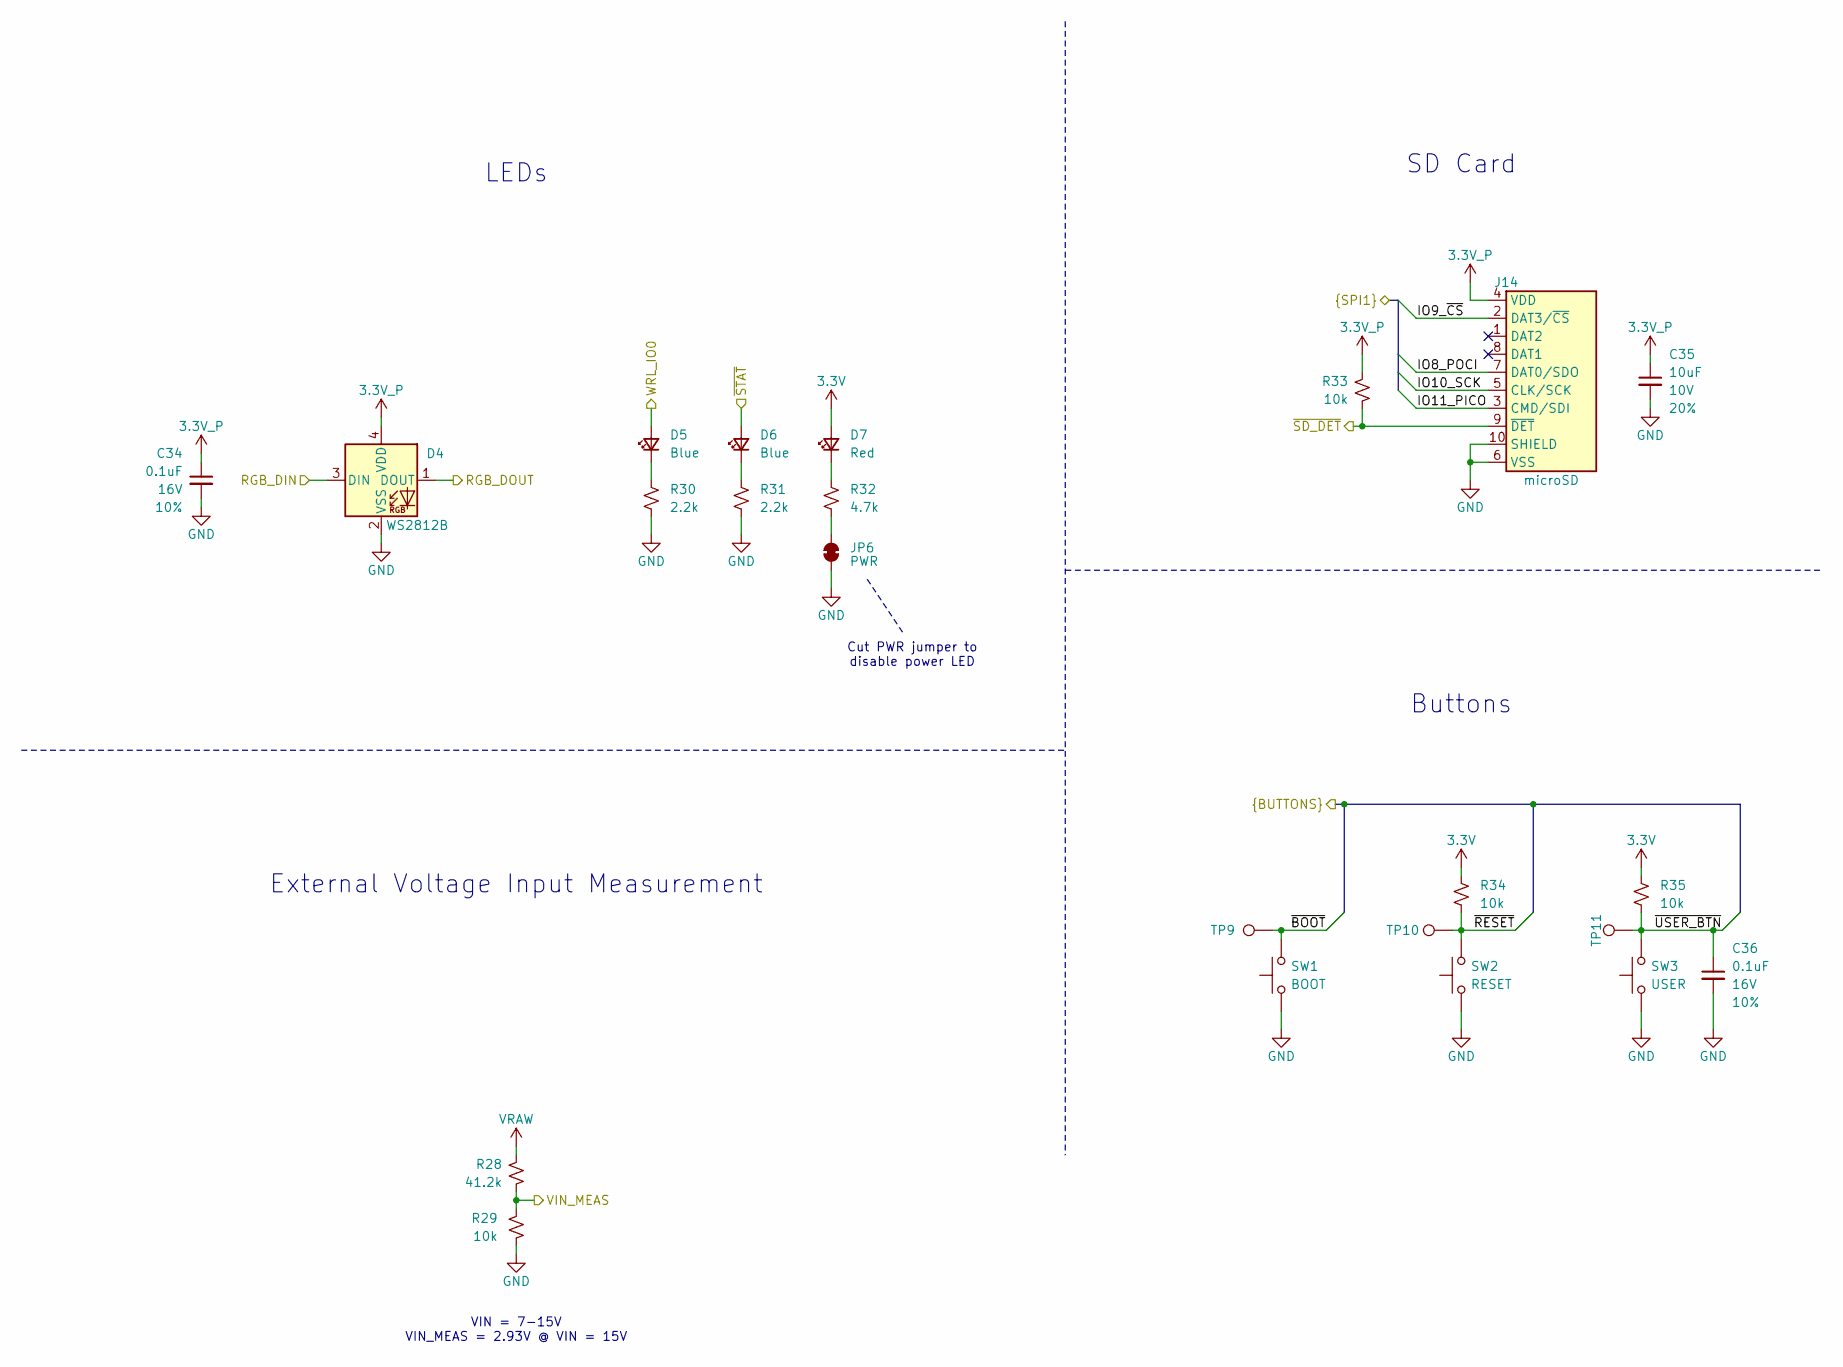
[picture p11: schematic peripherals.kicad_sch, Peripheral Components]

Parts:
C34, C36: 0.1uF; C_0402_1005Metric; Voltage 16V; Tolerance 10%
C35: 10uF; C_0603_1608Metric; Voltage 10V; Tolerance 20%
D4: WS2812B; WS2812_2020
D5, D6: Blue; LED_0603_1608Metric_Blue
D7: Red; LED_0603_1608Metric_Red
J14: microSD; microSD_External_Pin
JP6: PWR; Jumper_2_NC_Trace
R28: 41.2k; R_0402_1005Metric
R29, R33, R34, R35: 10k; R_0402_1005Metric
R30, R31: 2.2k; R_0402_1005Metric
R32: 4.7k; R_0402_1005Metric
SW1: BOOT; Push_SMD_5.2x5.2mm_h2.5mm
SW2: RESET; Push_SMD_5.2x5.2mm_h2.5mm
SW3: USER; Push_SMD_5.2x5.2mm_h2.5mm
TP9, TP10, TP11: 1.0mm; TestPoint-1.0mm

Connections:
3.3V: D7.2 (A), R34.2, R35.2; also elsewhere on the board
3.3V_P: C34.1, C35.1, D4.4 (VDD), J14.4 (VDD), R33.2; also elsewhere on the board
/Core/IO8_POCI: J14.7 (DAT0/SDO); also elsewhere on the board
/Core/IO9_~CS: J14.2 (DAT3/~CS); also elsewhere on the board
/Core/IO10_SCK: J14.5 (CLK/SCK); also elsewhere on the board
/Core/IO11_PICO: J14.3 (CMD/SDI); also elsewhere on the board
/Core/RGB_DIN: D4.3 (DIN); also elsewhere on the board
/Core/VIN_MEAS: R28.1, R29.2; also elsewhere on the board
/Core/WRL_IO0: D5.2 (A); also elsewhere on the board
/Core/~BOOT: SW1.2, TP9.1; also elsewhere on the board
/Core/~RESET: R34.1, SW2.2, TP10.1; also elsewhere on the board
/Core/~SD_DET: J14.9 (~DET), R33.1; also elsewhere on the board
/Core/~STAT: D6.2 (A); also elsewhere on the board
/Core/~USER_BTN: C36.1, R35.1, SW3.2, TP11.1; also elsewhere on the board
/RGB_DOUT: D4.1 (DOUT); also elsewhere on the board
GND: C34.2, C35.2, C36.2, D4.2 (VSS), J14.6 (VSS), J14.10 (SHIELD), JP6.1 (A), R29.1, R30.1, R31.1, SW1.1, SW2.1, SW3.1; also elsewhere on the board
unnamed: D5.1 (K), R30.2
unnamed: D6.1 (K), R31.2
unnamed: D7.1 (K), R32.2
unnamed: JP6.2 (B), R32.1
VRAW: R28.2; also elsewhere on the board

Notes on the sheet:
Buttons
VIN = 7-15V VIN_MEAS = 2.93V @ VIN = 15V
SD Card
Cut PWR jumper to disable power LED
LEDs
External Voltage Input Measurement

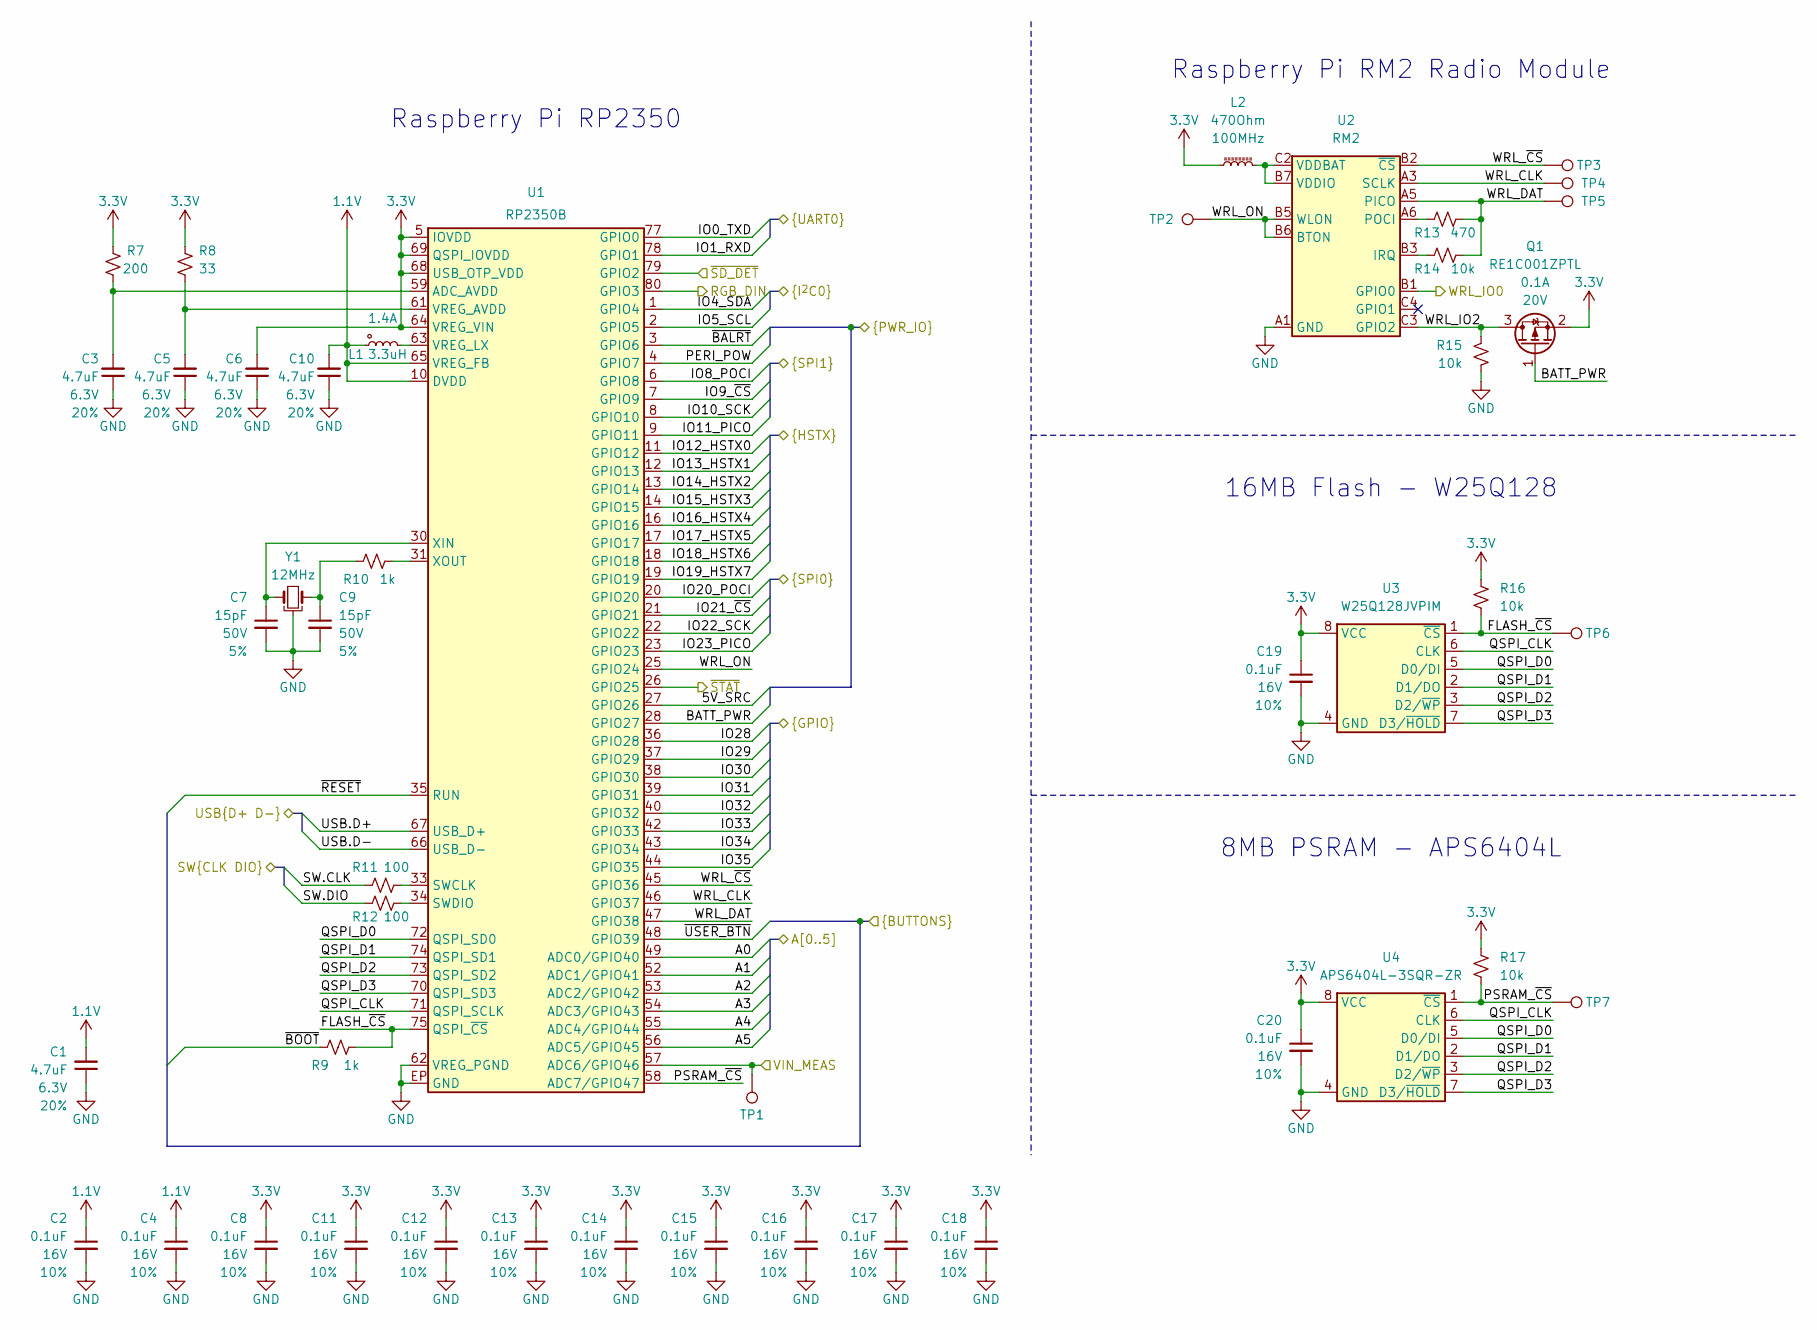
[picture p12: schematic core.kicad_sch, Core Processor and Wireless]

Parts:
C1, C3, C5, C6, C10: 4.7uF; C_0402_1005Metric; Voltage 6.3V; Tolerance 20%
C2, C4, C8, C11, C12, C13, C14, C15, C16, C17, C18, C19, C20: 0.1uF; C_0402_1005Metric; Voltage 16V; Tolerance 10%
C7, C9: 15pF; C_0402_1005Metric; Voltage 50V; Tolerance 5%
L1: 3.3uH; 0806_Polarized
L2: 470Ohm; C_0603_1608Metric
Q1: RE1C001ZPTL; SC-89 SOT-490
R7: 200; R_0402_1005Metric
R8: 33; R_0402_1005Metric
R9, R10: 1k; R_0402_1005Metric
R11, R12: 100; R_0402_1005Metric
R13: 470; R_0402_1005Metric
R14, R15, R16, R17: 10k; R_0402_1005Metric
TP1, TP2, TP3, TP4, TP5, TP6, TP7: 1.0mm; TestPoint-1.0mm
U1: RP2350B; QFN-80-1EP_10x10mm_P0.4mm_EP3.4x3.4mm
U2: RM2; RM2_Tight
U3: W25Q128JVPIM; WDFN-8_6x5mm-SkinnyCenterPad
U4: APS6404L-3SQR-ZR; USON-8_3x2mm-SkinnyCenterPad
Y1: 12MHz; Crystal_SMD_2.5x2.0mm

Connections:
1.1V: C1.2, C2.1, C4.1, C10.2, L1.1, U1.10 (DVDD), U1.32 (DVDD), U1.51 (DVDD), U1.65 (VREG_FB)
3.3V: C6.2, C8.1, C11.1, C12.1, C13.1, C14.1, C15.1, C16.1, C17.1, C18.1, C19.1, C20.1, L2.1, Q1.2 (S), R7.2, R8.2, R16.2, R17.2, U1.5 (IOVDD), U1.15 (IOVDD), U1.24 (IOVDD), U1.29 (IOVDD), U1.41 (IOVDD), U1.50 (IOVDD), U1.60 (IOVDD), U1.64 (VREG_VIN), U1.68 (USB_OTP_VDD), U1.69 (QSPI_IOVDD), U1.76 (IOVDD), U3.8 (VCC), U4.8 (VCC); also elsewhere on the board
/A0: U1.49 (ADC0/GPIO40); also elsewhere on the board
/A1: U1.52 (ADC1/GPIO41); also elsewhere on the board
/A2: U1.53 (ADC2/GPIO42); also elsewhere on the board
/A3: U1.54 (ADC3/GPIO43); also elsewhere on the board
/A4: U1.55 (ADC4/GPIO44); also elsewhere on the board
/A5: U1.56 (ADC5/GPIO45); also elsewhere on the board
/Core/5V_SRC: U1.27 (GPIO26); also elsewhere on the board
/Core/BATT_PWR: Q1.1 (G), U1.28 (GPIO27); also elsewhere on the board
/Core/FLASH_~CS: R9.1, R16.1, TP6.1, U1.75 (QSPI_~CS), U3.1 (~CS)
/Core/IO8_POCI: U1.6 (GPIO8); also elsewhere on the board
/Core/IO9_~CS: U1.7 (GPIO9); also elsewhere on the board
/Core/IO10_SCK: U1.8 (GPIO10); also elsewhere on the board
/Core/IO11_PICO: U1.9 (GPIO11); also elsewhere on the board
/Core/IO12_HSTX0: U1.11 (GPIO12); also elsewhere on the board
/Core/IO13_HSTX1: U1.12 (GPIO13); also elsewhere on the board
/Core/IO14_HSTX2: U1.13 (GPIO14); also elsewhere on the board
/Core/IO15_HSTX3: U1.14 (GPIO15); also elsewhere on the board
/Core/IO16_HSTX4: U1.16 (GPIO16); also elsewhere on the board
/Core/IO17_HSTX5: U1.17 (GPIO17); also elsewhere on the board
/Core/IO18_HSTX6: U1.18 (GPIO18); also elsewhere on the board
/Core/IO19_HSTX7: U1.19 (GPIO19); also elsewhere on the board
/Core/PERI_POW: U1.4 (GPIO7); also elsewhere on the board
/Core/PSRAM_~CS: R17.1, TP7.1, U1.58 (ADC7/GPIO47), U4.1 (~CS)
/Core/QSPI_CLK: U1.71 (QSPI_SCLK), U3.6 (CLK), U4.6 (CLK)
/Core/QSPI_D0: U1.72 (QSPI_SD0), U3.5 (D0/DI), U4.5 (D0/DI)
/Core/QSPI_D1: U1.74 (QSPI_SD1), U3.2 (D1/DO), U4.2 (D1/DO)
/Core/QSPI_D2: U1.73 (QSPI_SD2), U3.3 (D2/~WP), U4.3 (D2/~WP)
/Core/QSPI_D3: U1.70 (QSPI_SD3), U3.7 (D3/~HOLD), U4.7 (D3/~HOLD)
/Core/RGB_DIN: U1.80 (GPIO3); also elsewhere on the board
/Core/SW.CLK: R11.1; also elsewhere on the board
/Core/SW.DIO: R12.1; also elsewhere on the board
/Core/USB.D+: U1.67 (USB_D+); also elsewhere on the board
/Core/USB.D-: U1.66 (USB_D-); also elsewhere on the board
/Core/VIN_MEAS: TP1.1, U1.57 (ADC6/GPIO46); also elsewhere on the board
/Core/WRL_CLK: TP4.1, U1.46 (GPIO37), U2.A3 (SCLK)
/Core/WRL_DAT: R13.2, R14.2, TP5.1, U1.47 (GPIO38), U2.A5 (PICO)
/Core/WRL_IO0: U2.B1 (GPIO0); also elsewhere on the board
/Core/WRL_IO2: Q1.3 (D), R15.2, U2.C3 (GPIO2)
/Core/WRL_ON: TP2.1, U1.25 (GPIO24), U2.B5 (WLON), U2.B6 (BTON)
/Core/WRL_~CS: TP3.1, U1.45 (GPIO36), U2.B2 (~CS)
/Core/~BALRT: U1.3 (GPIO6); also elsewhere on the board
/Core/~BOOT: R9.2; also elsewhere on the board
/Core/~RESET: U1.35 (RUN); also elsewhere on the board
/Core/~SD_DET: U1.79 (GPIO2); also elsewhere on the board
/Core/~STAT: U1.26 (GPIO25); also elsewhere on the board
/Core/~USER_BTN: U1.48 (GPIO39); also elsewhere on the board
/IO0_TXD: U1.77 (GPIO0); also elsewhere on the board
/IO1_RXD: U1.78 (GPIO1); also elsewhere on the board
/IO4_SDA: U1.1 (GPIO4); also elsewhere on the board
/IO5_SCL: U1.2 (GPIO5); also elsewhere on the board
/IO20_POCI: U1.20 (GPIO20); also elsewhere on the board
/IO21_~CS: U1.21 (GPIO21); also elsewhere on the board
/IO22_SCK: U1.22 (GPIO22); also elsewhere on the board
/IO23_PICO: U1.23 (GPIO23); also elsewhere on the board
/IO28: U1.36 (GPIO28); also elsewhere on the board
/IO29: U1.37 (GPIO29); also elsewhere on the board
/IO30: U1.38 (GPIO30); also elsewhere on the board
/IO31: U1.39 (GPIO31); also elsewhere on the board
/IO32: U1.40 (GPIO32); also elsewhere on the board
/IO33: U1.42 (GPIO33); also elsewhere on the board
/IO34: U1.43 (GPIO34); also elsewhere on the board
/IO35: U1.44 (GPIO35); also elsewhere on the board
GND: C1.1, C2.2, C3.1, C4.2, C5.1, C6.1, C7.2, C8.2, C9.2, C10.1, C11.2, C12.2, C13.2, C14.2, C15.2, C16.2, C17.2, C18.2, C19.2, C20.2, R15.1, U1.62 (VREG_PGND), U1.EP (GND), U2.A1 (GND), U2.A4 (GND), U2.A7 (GND), U2.B4 (GND), U2.C1 (GND), U2.C7 (GND), U3.4 (GND), U3.EPAD (GND), U4.4 (GND), U4.9 (GND), Y1.2, Y1.4; also elsewhere on the board
unnamed: C9.1, R10.1, Y1.3
unnamed: C3.2, R7.1, U1.59 (ADC_AVDD)
unnamed: R11.2, U1.33 (SWCLK)
unnamed: R12.2, U1.34 (SWDIO)
unnamed: C5.2, R8.1, U1.61 (VREG_AVDD)
unnamed: L1.2, U1.63 (VREG_LX)
unnamed: C7.1, U1.30 (XIN), Y1.1
unnamed: R10.2, U1.31 (XOUT)
unnamed: R14.1, U2.B3 (IRQ)
unnamed: R13.1, U2.A6 (POCI)
unnamed: L2.2, U2.B7 (VDDIO), U2.C2 (VDDBAT)

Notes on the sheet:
16MB Flash - W25Q128
8MB PSRAM - APS6404L
Raspberry Pi RP2350
Raspberry Pi RM2 Radio Module

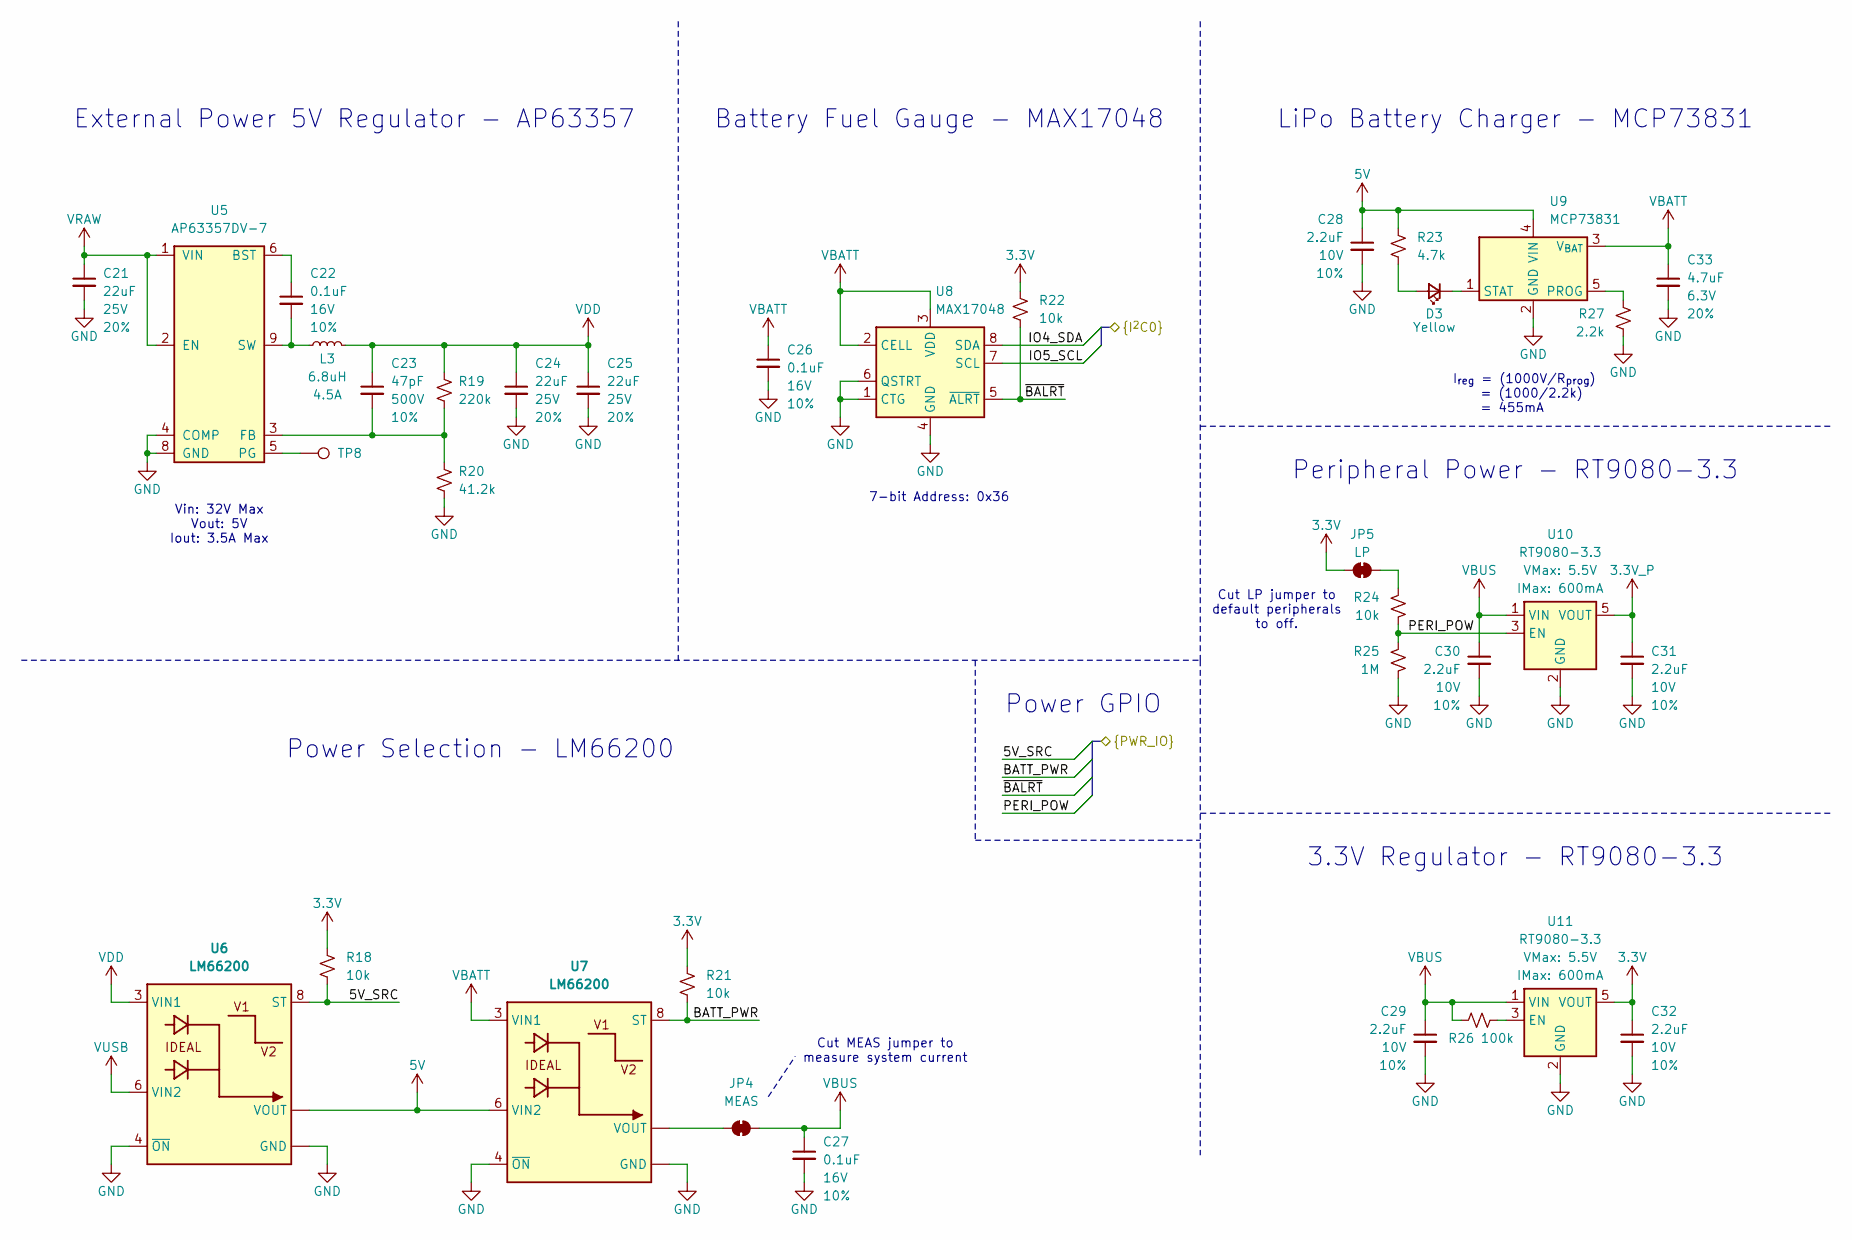
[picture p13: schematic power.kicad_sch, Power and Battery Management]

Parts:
C21, C24, C25: 22uF; C_0805_2012Metric; Voltage 25V; Tolerance 20%
C22, C26, C27: 0.1uF; C_0402_1005Metric; Voltage 16V; Tolerance 10%
C23: 47pF; C_0402_1005Metric; Voltage 500V; Tolerance 10%
C28, C29, C30, C31, C32: 2.2uF; C_0402_1005Metric; Voltage 10V; Tolerance 10%
C33: 4.7uF; C_0402_1005Metric; Voltage 6.3V; Tolerance 20%
D3: Yellow; LED_0603_1608Metric_Yellow
JP4: MEAS; Jumper_2_PTH_SMD_Combo-NC
JP5: LP; Jumper_2_NC_Trace
L3: 6.8uH; Inductor_7.3x6.6mm
R18, R21, R22, R24: 10k; R_0402_1005Metric
R19: 220k; R_0402_1005Metric
R20: 41.2k; R_0402_1005Metric
R23: 4.7k; R_0402_1005Metric
R25: 1M; R_0402_1005Metric
R26: 100k; R_0402_1005Metric
R27: 2.2k; R_0402_1005Metric
TP8: 1.0mm; TestPoint-1.0mm
U5: AP63357DV-7; PowerVFDFN-13
U6, U7: LM66200; SOT-583-8
U8: MAX17048; DFN-8
U9: MCP73831; SOT23-5
U10, U11: RT9080-3.3; SOT23-5

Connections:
3.3V: C32.1, JP5.1 (A), R18.2, R21.2, R22.2, U11.5 (VOUT); also elsewhere on the board
3.3V_P: C31.1, U10.5 (VOUT); also elsewhere on the board
5V: C28.1, R23.2, U6.2 (VOUT), U6.7 (VOUT), U7.6 (VIN2), U9.4 (VIN); also elsewhere on the board
/Core/5V_SRC: R18.1, U6.8 (ST); also elsewhere on the board
/Core/BATT_PWR: R21.1, U7.8 (ST); also elsewhere on the board
/Core/PERI_POW: R24.2, R25.2, U10.3 (EN); also elsewhere on the board
/Core/~BALRT: R22.1, U8.5 (~ALRT); also elsewhere on the board
/IO4_SDA: U8.8 (SDA); also elsewhere on the board
/IO5_SCL: U8.7 (SCL); also elsewhere on the board
GND: C21.2, C24.2, C25.2, C26.2, C27.2, C28.2, C29.2, C30.2, C31.2, C32.2, C33.2, R20.1, R25.1, R27.1, U5.4 (COMP), U5.8 (GND), U6.1 (GND), U6.4 (~ON), U6.5 (GND), U7.1 (GND), U7.4 (~ON), U7.5 (GND), U8.1 (CTG), U8.4 (GND), U8.6 (QSTRT), U8.9 (GND), U9.2 (GND), U10.2 (GND), U11.2 (GND); also elsewhere on the board
unnamed: D3.2 (A), R23.1
unnamed: D3.1 (K), U9.1 (STAT)
unnamed: JP4.1 (A), U7.2 (VOUT), U7.7 (VOUT)
unnamed: JP5.2 (B), R24.1
unnamed: C22.1, U5.6 (BST)
unnamed: C23.2, R19.1, R20.2, U5.3 (FB)
unnamed: C22.2, L3.1, U5.7 (NC), U5.9 (SW)
unnamed: TP8.1, U5.5 (PG)
unnamed: R27.2, U9.5 (PROG)
unnamed: R26.2, U11.3 (EN)
VBATT: C26.1, C33.1, U7.3 (VIN1), U8.2 (CELL), U8.3 (VDD), U9.3 (V_{BAT}); also elsewhere on the board
VBUS: C27.1, C29.1, C30.1, JP4.2 (B), R26.1, U10.1 (VIN), U11.1 (VIN)
VDD: C23.1, C24.1, C25.1, L3.2, R19.2, U6.3 (VIN1)
VRAW: C21.1, U5.1 (VIN), U5.2 (EN); also elsewhere on the board
VUSB: U6.6 (VIN2); also elsewhere on the board

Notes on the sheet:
Cut LP jumper to default peripherals to off.
Power Selection - LM66200
Battery Fuel Gauge - MAX17048
I_{reg} = (1000V/R_{prog}) = (1000/2.2k) = 455mA
External Power 5V Regulator - AP63357
3.3V Regulator - RT9080-3.3
Power GPIO
LiPo Battery Charger - MCP73831
Peripheral Power - RT9080-3.3
Vin: 32V Max Vout: 5V Iout: 3.5A Max
Cut MEAS jumper to measure system current
7-bit Address: 0x36

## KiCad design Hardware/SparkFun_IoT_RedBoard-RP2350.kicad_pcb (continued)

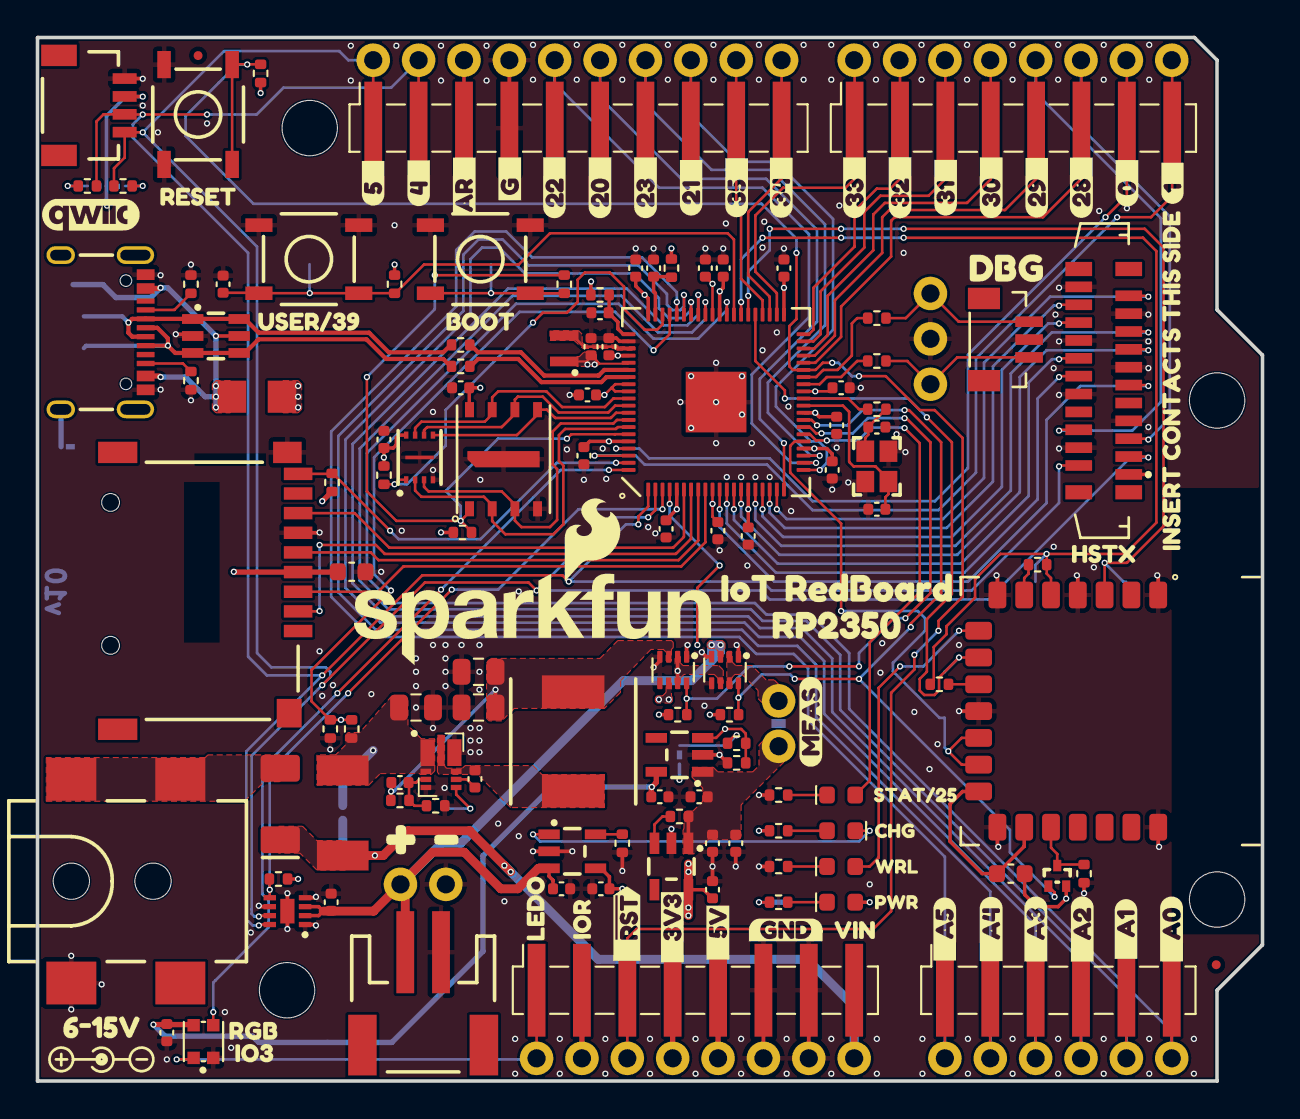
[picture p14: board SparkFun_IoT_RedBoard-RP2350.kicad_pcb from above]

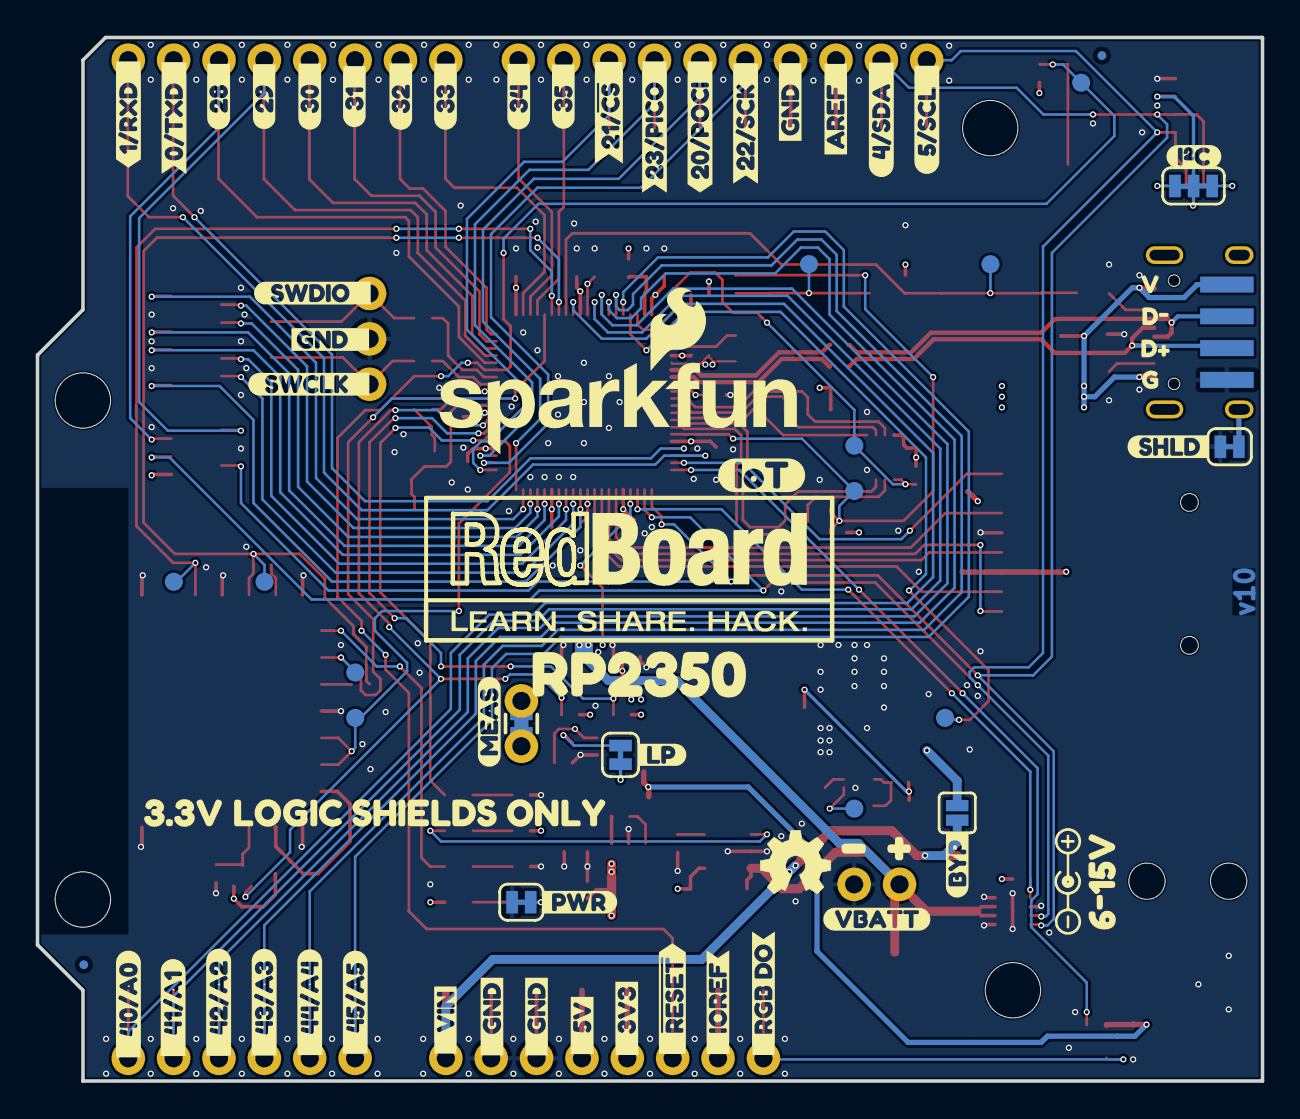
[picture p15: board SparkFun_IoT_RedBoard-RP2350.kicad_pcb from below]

Board: 4 copper layers, 68.6 x 58.4 mm, 244 parts (74 on the bottom side), 108 nets.

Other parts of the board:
Ref**: Val**; POLARITY_MARKING_CENTER_POSITIVE
Ref**#2: Val**; OSHW_Logo_4mm
Ref**#3: Val**; POLARITY_MARKING_CENTER_POSITIVE
kibuzzard-67A3E0D1: G***; kibuzzard-67A3E0D1
kibuzzard-67A3E1A1: G***; kibuzzard-67A3E1A1
kibuzzard-67A3E1A7: G***; kibuzzard-67A3E1A7
kibuzzard-67A3E1AE: G***; kibuzzard-67A3E1AE
kibuzzard-67A3E1B5: G***; kibuzzard-67A3E1B5
kibuzzard-67A3E1BE: G***; kibuzzard-67A3E1BE
kibuzzard-67A3E1C5: G***; kibuzzard-67A3E1C5
kibuzzard-67A3E1CD: G***; kibuzzard-67A3E1CD
kibuzzard-67A3E1E0: G***; kibuzzard-67A3E1E0
kibuzzard-67A3E1FA: G***; kibuzzard-67A3E1FA
kibuzzard-67A3E2A5: G***; kibuzzard-67A3E2A5
kibuzzard-67A3E2C6: G***; kibuzzard-67A3E2C6
kibuzzard-67A3E4A3: G***; kibuzzard-67A3E4A3
kibuzzard-67A3E4D1: G***; kibuzzard-67A3E4D1
kibuzzard-67A3E09E: G***; kibuzzard-67A3E09E
kibuzzard-67A3E12A: G***; kibuzzard-67A3E12A
kibuzzard-67A3E17B: G***; kibuzzard-67A3E17B
kibuzzard-67A3E20D: G***; kibuzzard-67A3E20D
kibuzzard-67A3E24D: G***; kibuzzard-67A3E24D
kibuzzard-67A3E25A: G***; kibuzzard-67A3E25A
kibuzzard-67A3E26A: G***; kibuzzard-67A3E26A
kibuzzard-67A3E43C: G***; kibuzzard-67A3E43C
kibuzzard-67A3E45D: G***; kibuzzard-67A3E45D
kibuzzard-67A3E112: G***; kibuzzard-67A3E112
kibuzzard-67A3E140: G***; kibuzzard-67A3E140
kibuzzard-67A3E168: G***; kibuzzard-67A3E168
kibuzzard-67A3E171: G***; kibuzzard-67A3E171
kibuzzard-67A3E183: G***; kibuzzard-67A3E183
kibuzzard-67A3E201: G***; kibuzzard-67A3E201
kibuzzard-67A3E235: G***; kibuzzard-67A3E235
kibuzzard-67A3E254: G***; kibuzzard-67A3E254
kibuzzard-67A3E263: G***; kibuzzard-67A3E263
kibuzzard-67A3E284: G***; kibuzzard-67A3E284
kibuzzard-67A3E455: G***; kibuzzard-67A3E455
kibuzzard-67A3F3F2: G***; kibuzzard-67A3F3F2
kibuzzard-67A3F4AA: G***; kibuzzard-67A3F4AA
kibuzzard-67A3F4E6: G***; kibuzzard-67A3F4E6
kibuzzard-67A3F5C2: G***; kibuzzard-67A3F5C2
kibuzzard-67A3F5D5: G***; kibuzzard-67A3F5D5
kibuzzard-67A3F5FB: G***; kibuzzard-67A3F5FB
kibuzzard-67A3F6A9: G***; kibuzzard-67A3F6A9
kibuzzard-67A3F6CD: G***; kibuzzard-67A3F6CD
kibuzzard-67A3F6E9: G***; kibuzzard-67A3F6E9
kibuzzard-67A3F7A5: G***; kibuzzard-67A3F7A5
kibuzzard-67A3F7B2: G***; kibuzzard-67A3F7B2
kibuzzard-67A3F7C3: G***; kibuzzard-67A3F7C3
kibuzzard-67A3F7D3: G***; kibuzzard-67A3F7D3
kibuzzard-67A3F9C4: G***; kibuzzard-67A3F9C4
kibuzzard-67A3F9DC: G***; kibuzzard-67A3F9DC
kibuzzard-67A3F59C: G***; kibuzzard-67A3F59C
kibuzzard-67A3F62C: G***; kibuzzard-67A3F62C
kibuzzard-67A3F63E: G***; kibuzzard-67A3F63E
kibuzzard-67A3F64D: G***; kibuzzard-67A3F64D
kibuzzard-67A3F71F: G***; kibuzzard-67A3F71F
kibuzzard-67A3F72C: G***; kibuzzard-67A3F72C
kibuzzard-67A3F73E: G***; kibuzzard-67A3F73E
kibuzzard-67A3F74E: G***; kibuzzard-67A3F74E
kibuzzard-67A3F78A: G***; kibuzzard-67A3F78A
kibuzzard-67A3F532: G***; kibuzzard-67A3F532
kibuzzard-67A3F552: G***; kibuzzard-67A3F552
kibuzzard-67A3F565: G***; kibuzzard-67A3F565
kibuzzard-67A3F577: G***; kibuzzard-67A3F577
kibuzzard-67A3F625: G***; kibuzzard-67A3F625
kibuzzard-67A3F633: G***; kibuzzard-67A3F633
kibuzzard-67A3F639: G***; kibuzzard-67A3F639
kibuzzard-67A3F646: G***; kibuzzard-67A3F646
kibuzzard-67A3F657: G***; kibuzzard-67A3F657
kibuzzard-67A3F666: G***; kibuzzard-67A3F666
kibuzzard-67A3F682: G***; kibuzzard-67A3F682
kibuzzard-67A3F699: G***; kibuzzard-67A3F699
kibuzzard-67A3F769: G***; kibuzzard-67A3F769
kibuzzard-67A3F773: G***; kibuzzard-67A3F773
kibuzzard-67A3F799: G***; kibuzzard-67A3F799
kibuzzard-67A657F3: G***; kibuzzard-67A657F3
kibuzzard-67A657FD: G***; kibuzzard-67A657FD
kibuzzard-6761DE89: G***; kibuzzard-6761DE89
kibuzzard-6761DE91: G***; kibuzzard-6761DE91
kibuzzard-6765AF34: G***; kibuzzard-6765AF34
kibuzzard-6765AF51: G***; kibuzzard-6765AF51
kibuzzard-6765B674: G***; kibuzzard-6765B674
kibuzzard-67608A8F: G***; kibuzzard-67608A8F
kibuzzard-67608A60: G***; kibuzzard-67608A60
kibuzzard-67608A88: G***; kibuzzard-67608A88
kibuzzard-67608AA5: G***; kibuzzard-67608AA5
kibuzzard-67608E95: G***; kibuzzard-67608E95
kibuzzard-67608F94: G***; kibuzzard-67608F94
kibuzzard-675766BF: G***; kibuzzard-675766BF
kibuzzard-676080F0: G***; kibuzzard-676080F0
kibuzzard-676083AD, kibuzzard-676083AD#2: G***; kibuzzard-676083AD
kibuzzard-676084E8: G***; kibuzzard-676084E8
kibuzzard-676098CD: G***; kibuzzard-676098CD
kibuzzard-6760897E: G***; kibuzzard-6760897E
kibuzzard-67576710: G***; kibuzzard-67576710
kibuzzard-67576718: G***; kibuzzard-67576718
kibuzzard-67608476: G***; kibuzzard-67608476
kibuzzard-67608507: G***; kibuzzard-67608507
kibuzzard-67608599: G***; kibuzzard-67608599
kibuzzard-67608612: G***; kibuzzard-67608612
kibuzzard-67608662: G***; kibuzzard-67608662
kibuzzard-67608910: G***; kibuzzard-67608910

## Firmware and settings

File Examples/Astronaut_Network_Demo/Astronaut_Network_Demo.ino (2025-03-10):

#include <WiFi.h>
#include <ArduinoJson.h>
#include <FastLED.h>
#include <cstdint>

// WiFi variables
#ifndef STASSID
#define STASSID "SSID"
#define STAPSK  "PASSWORD"
#endif // !STASSID

const char* ssid = STASSID;
const char* password = STAPSK;

const char* host = "corquaid.github.io";
const uint16_t port = 443;

WiFiMulti multi;

// LED variables
#define NUM_LEDS 1
#define DATA_PIN PIN_NEOPIXEL
#define LED_TYPE WS2812
#define COLOR_ORDER GRB
#define LED_BRIGHTNESS 30

CRGB leds[NUM_LEDS];

void setup() {
    Serial.begin(115200);

    // Uncomment to wait for serial monitor
    // while(!Serial) { delay(100);};

    // Setup RGB LED.
    FastLED.addLeds<LED_TYPE, DATA_PIN, COLOR_ORDER>(leds, NUM_LEDS);
    FastLED.setBrightness(LED_BRIGHTNESS);

    // Set the LED Red while connecting to WiFi.
    FastLED.showColor(CRGB::Red);

    Serial.print("Connecting to ");
    Serial.println(ssid);

    // Connect to a WiFi network.
    multi.addAP(ssid, password);

    if(multi.run() != WL_CONNECTED) {
        Serial.println(F("Unable to connect to network, rebooting in 10 seconds..."));
        delay(10000);
        rp2040.reboot();
    }

    Serial.println(F("Connected to network"));
    Serial.println(F("IP address: "));
    Serial.println(WiFi.localIP());

    // Create a WiFi clent. It has to be a "secure" client because the server we are connecting to uses HTTPS.
    BearSSL::WiFiClientSecure client;
    client.setTimeout(10000);
    // Doesn't validate the chain, just accept whatever is given. VERY INSECURE!
    client.setInsecure();
    // Connect to server.
    if(!client.connect(host, port)) {
        Serial.println(F("Connection failed"));
        delay(5000);
        return;
    }

    Serial.println(F("Connected!"));

    // Set the LED to blue while downloading data.
    FastLED.showColor(CRGB::Blue);

    Serial.println(F("Downloading list of astronauts currently in space..."));
    
    // Send HTTP GET request
    client.println(F("GET /international-space-station-APIs/JSON/people-in-space.json HTTP/1.0"));
    client.println(F("Host: corquaid.github.io"));
    client.println(F("Connection: close"));
    
    if(client.println() == 0) {
        Serial.println(F("Failed to send request"));
        client.stop();
        return;
    }

    // Check HTTP status
    char status[32] = {0};
    client.readBytesUntil('\r', status, sizeof(status));
    if(strncmp(status + 9, "200 OK", sizeof(status)) != 0) {
        Serial.print(F("Unexpected response: "));
        Serial.println(status);
        client.stop();
        return;
    }

    // Skip HTTP headers
    const char endOfHeaders[] = "\r\n\r\n";
    if(!client.find(endOfHeaders)) {
        Serial.println(F("Invalid response"));
        client.stop();
        return;
    }

    // Parse JSON
    JsonDocument doc;
    DeserializationError error = deserializeJson(doc, client);
    if(error) {
        Serial.print(F("deserializeJson() failed: "));
        Serial.println(error.f_str());
        client.stop();
        return;
    }

    // Print number of astronauts in space and their names.
    int numberOfPeople = doc[F("number")];

    Serial.print(F("There are "));
    Serial.print(numberOfPeople);
    Serial.println(F(" astronauts in space."));

    for(JsonObject people_item : doc[F("people")].as<JsonArray>()) {
        int people_item_id = people_item[F("id")];
        const char* people_item_name = people_item[F("name")];
        Serial.print(people_item_id);
        Serial.print(F(": "));
        Serial.println(people_item_name);
    }

    // Set the LED to green to indicate success.
    FastLED.showColor(CRGB::Green);
}

void loop() {}

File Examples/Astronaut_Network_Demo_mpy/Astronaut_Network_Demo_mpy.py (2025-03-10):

import network
import urequests
import time
import neopixel
import machine

# Set up the NeoPixel LED
pin = machine.Pin("NEOPIXEL")
led = neopixel.NeoPixel(pin, 1)

# Set the LED to red while connecting to WiFi
led[0] = (255, 0, 0)
led.write()

# Connect to a WiFi network
wlan = network.WLAN(network.STA_IF)
wlan.active(True)
wlan.connect('WIFI_NETWORK', 'WIFI_PASSWORD')

# Wait for the connection to complete
print("Waiting for connection...")
while not wlan.isconnected():
    time.sleep(1)
    print('.', sep='', end='', )
print('Connected!')

# Set the LED to blue while downloading data
led[0] = (0, 0, 255)
led.write()

# Download the list of astronauts currently in space
print('Downloading list of astronauts currently in space...')
astronauts = urequests.get("https://corquaid.github.io/international-space-station-APIs/JSON/people-in-space.json").json()

# Print the number of astronauts and their names
number = astronauts['number']
print('There are', number, 'astronauts in space.')
for i in range(number):
    print(i+1, astronauts['people'][i]['name'])

# Set the LED to green to indicate success
led[0] = (0, 255, 0)
led.write()

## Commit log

2024-12-16 v01 ready for review
    [SparkFun_IoT_RedBoard-RP2350.kicad_pcb, SparkFun_IoT_RedBoard-RP2350.kicad_sch, core.kicad_sch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]
2024-12-17 Update v01 from checklist. Added measures.
    [SparkFun_IoT_RedBoard-RP2350.kicad_pcb, SparkFun_IoT_RedBoard-RP2350.kicad_sch, core.kicad_sch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]
2024-12-18 Update parts with 3D models.
    [SparkFun_IoT_RedBoard-RP2350.kicad_pcb]
2024-12-20 v01 post design review changes. Panelize/CAM.
    Remove F3.
    Added switched power for qwiic, rgb, sd.
    Update USB diode for prod friendly package.
    Added debounce cap on User button.
    Swap user and boot buttons.
    Make F2 a smaller package.
    Renumber GPIO and use contiguous numbers for PIO purposes.
    Swap inputs on Ideal diodes for battery powered current purposes.
    Move USB termination resistors closer to MCU.
    Fixed A0-A5 ordering.
    Update silks.
    Add mask to middle of SMD GPIOs.
    [SparkFun_IoT_RedBoard-RP2350.kicad_pcb, SparkFun_IoT_RedBoard-RP2350.kicad_sch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]
2025-02-06 Update for reds
    Change version number to v10.
    Make user button number correct.
    Rotate HSTX conn 180 degrees electrically.
    Add silk for HSTX contact direction.
    Increase silk text size where it made sense.
    Increase silk label length on PTHs.
    Panelize and CAM.
    [SparkFun_IoT_RedBoard-RP2350.kicad_pcb, SparkFun_IoT_RedBoard-RP2350.kicad_sch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]
2025-02-07 Update post reds review
    Added SOT489
    Move vias around so they don't interfere with silk
    Change Barrel Jack voltage range.
    Increase VUSB trace width.
    Add silk to HSTX connector.
    Panelize & CAM.
    [SparkFun_IoT_RedBoard-RP2350.kicad_pcb, SparkFun_IoT_RedBoard-RP2350.kicad_sch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]
2025-02-13 Updated top paste layer
    [SparkFun_IoT_RedBoard-RP2350_panelized.GTP]
2025-03-10 Add Arduino Network demo.
2025-03-13 Docs Initial Review
    Initial review of docs update. Minor edits to existing .md files & adding board files to assets folder.
2025-03-17 Update Quick Start
    Adding Arduino code snippets.
2025-03-20 Minor Docs Update
    Re-uploading schematic & fixing datasheet typo.
2025-03-20 Schematic link fix
    Updating schematic filename to properly update.
2025-03-20 Update mkdocs.yml
    Removing unnecessary Hardware Assembly nav item.

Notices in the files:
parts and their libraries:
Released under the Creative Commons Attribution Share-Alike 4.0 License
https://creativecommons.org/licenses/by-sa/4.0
